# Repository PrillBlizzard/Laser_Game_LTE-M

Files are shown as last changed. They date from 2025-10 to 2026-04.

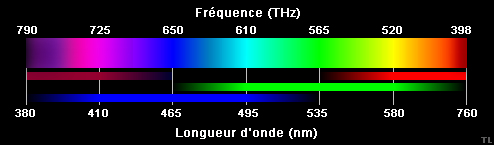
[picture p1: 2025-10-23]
Tests_Hardware/Test_laser_capteur/wavelength-2.png

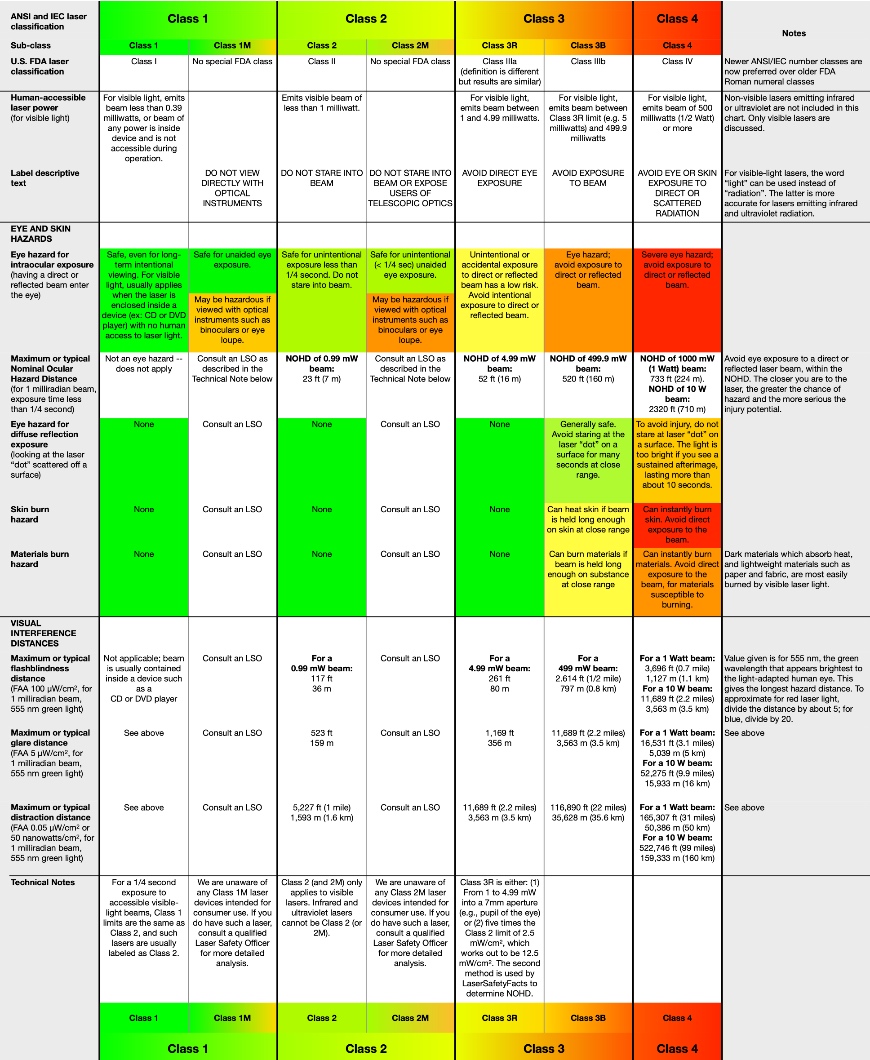
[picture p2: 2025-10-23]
Tests_Hardware/Test_laser_capteur/spreadsheet---laser-classes-870w.jpg

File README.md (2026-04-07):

# Laser_Game_LTE-M
Ce projet à été réalisé dans le cadre de mon projet de fin d'étude (PFE) de ma dernière année d'école d'ingénieur.

## Description
C'est un projet de dévellopement d'un équipement de Laser Game tirant en infrarouge et où l'équipement envoie des données sur un serveur via LTE-M.
Le prototype software est utilisé sur une carte de dévellopement nRF9151-DK.

## Arborescence 
Vous trouverez dans le dossier racine le dossier "Prog_Carte_Globale" correspondant au sur-dossier de l'application créer par l'extension nrfConnect pour VScode.
Vous trouverez aussi dans ce dossier mon compte-rendu de PFE : essentiel pour comprendre ce projet.

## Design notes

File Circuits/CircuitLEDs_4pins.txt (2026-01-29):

$ 1 7.8125e-7 0.1 50 5 43 5e-11
f 304 304 352 304 33 1.5 0.02
R 128 144 80 144 0 0 40 5 0 0 0.5
162 256 144 320 144 2 default-led 0 1 0 0.01
162 256 112 320 112 2 default-led 1 0 0 0.01
162 256 176 320 176 2 default-led 0 0 1 0.01
w 224 144 256 144 0
w 256 112 224 112 0
w 256 176 224 176 0
w 320 176 352 176 0
w 352 144 320 144 0
w 320 112 352 112 0
R 304 304 256 304 4 5 40000 1.8 0 0 0.5
g 352 320 352 384 0 0
w 352 192 352 288 0
r 224 112 128 112 0 100
r 224 144 128 144 0 100
r 224 176 128 176 0 100
w 128 112 128 144 0
w 128 176 128 144 0
w 480 192 480 288 0
g 480 320 480 384 0 0
R 432 304 384 304 4 5 40000 1.8 0 0 0.5
f 432 304 480 304 33 1.5 0.02
f 560 304 608 304 33 1.5 0.02
R 560 304 512 304 4 5 40000 1.8 0 0 0.5
g 608 320 608 384 0 0
w 608 192 608 288 0
w 352 176 352 192 0
w 352 144 480 144 0
w 480 144 480 192 0
w 352 112 608 112 0
w 608 112 608 192 0
o 2 1 0 4099 2.5 0.0125 0 2 2 3

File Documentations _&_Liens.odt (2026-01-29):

Docs :

- Photodiode/photoTransistor : https://www.digikey.fr/fr/articles/how-to-use-photodiodes-and-phototransistors-most-effectively
- https://www.digikey.com/en/articles/the-basics-of-photodiodes-and-phototransistors-and-how-to-apply-them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
- DECT NR+ : https://docs.nordicsemi.com/bundle/ncs-3.0.0/page/nrf/protocols/dect/index.html
  - https://docs.nordicsemi.com/bundle/ncs-3.0.0/page/nrf/app_dev/device_guides/nrf91/index.html#ug-nrf91
  - https://www.digikey.com/en/articles/use-an-lte-m-nb-iot-dect-nr-combination-dev-kit-wireless-iot-design
  - nrf9151 : https://docs.nordicsemi.com/bundle/ncs-3.0.0/page/zephyr/boards/nordic/nrf9151dk/doc/index.html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
  - dtr :
- Aduino pour tests :
  - Interruptions : https://docs.arduino.cc/language-reference/en/functions/external-interrupts/attachInterrupt/
  - Librairies tuto : https://docs.arduino.cc/learn/contributions/arduino-creating-library-guide/
  - I2C tuto : https://www.electronicwings.com/arduino/arduino-i2c
  - I2C librairie : https://github.com/Wh1teRabbitHU/Arduino-I2C/tree/master
  - Librarie réception IR : https://github.com/Arduino-IRremote/Arduino-IRremote/tree/master
- Transmission IR :
  - modulation NEC : https://sibotic.wordpress.com/wp-content/uploads/2013/12/adoh-necinfraredtransmissionprotocol-281113-1713-47344.pdf ou
  - doc recepteur IR ELEGOO Arduino (obsolète) : https://cours.polymtl.ca/inf1900/materiel/capteurs/specEtDoc/PNA4602.pdf
  - https://www.vishay.com/docs/82491/tsop382.pdf plutôt
  - Librairie capteur VCNL3040(DockyDock) : https://github.com/JenertsA/VCNL3040_Proximity_Sensor_Library/tree/master
  - Doc capteur VCNL3040(DockyDock) : https://www.vishay.com/docs/84917/vcnl3040.pdf
- nrf9151 :
  - Pin config : https://docs.nordicsemi.com/bundle/ps_nrf9151/page/pin.html
  - PWM : https://docs.nordicsemi.com/bundle/ps_nrf9151/page/pwm.html
  - Spec Générales : https://docs.nordicsemi.comn/bundle/ps_nrf9151/page/nRF9151_html5_keyfeatures.html (https://docs.nordicsemi.com/bundle/ps_nrf9151/page/nRF9151_html5_keyfeatures.html)

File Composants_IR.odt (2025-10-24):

Photo Transistor :

- https://www.digikey.fr/fr/products/detail/everlight-electronics-co-ltd/ALS-PT204-6C-L177/2675510
  - Traversant
  - Réponse spectral à 650 nm entre 80 % et 100 % ( <10 % entre 550 et 700 nm)
  - Documentation ok : https://eclass.uth.gr/modules/document/file.php/E-CE_U_269/Sensors/Sensors_%20Datasheets/KY-008-AZ-Delivery.pdf
- Optek / TT Electronics — OPB608R
  - https://www.digikey.fr/fr/products/detail/tt-electronics-optek-technology/OPB608R/1636987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

PhotoDiodes (+ rapides) :

- BPW34
  - https://www.digikey.fr/fr/products/detail/ams-osram-usa-inc/BPW34/607274

Diode Laser :

- KY-008 Laser Module
  - Datasheet : https://eclass.uth.gr/modules/document/file.php/E-CE_U_269/Sensors/Sensors_%20Datasheets/KY-008-AZ-Delivery.pdf
  - Où acheter ?
  - https://www.amazon.fr/Aihasd-KY-008-Capteur-Module-Arduino/dp/B00W3GS5Q0

Capteur Arduino :

- https://www.amazon.fr/ARCELI-Commutateur-capteur-r%C3%A9cepteur-Arduino/dp/B07RLNLN37

Résistances 7,5 kOhm

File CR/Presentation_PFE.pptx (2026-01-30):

## Final Project Presentation

Laser Tag System by Gaël Chauvet

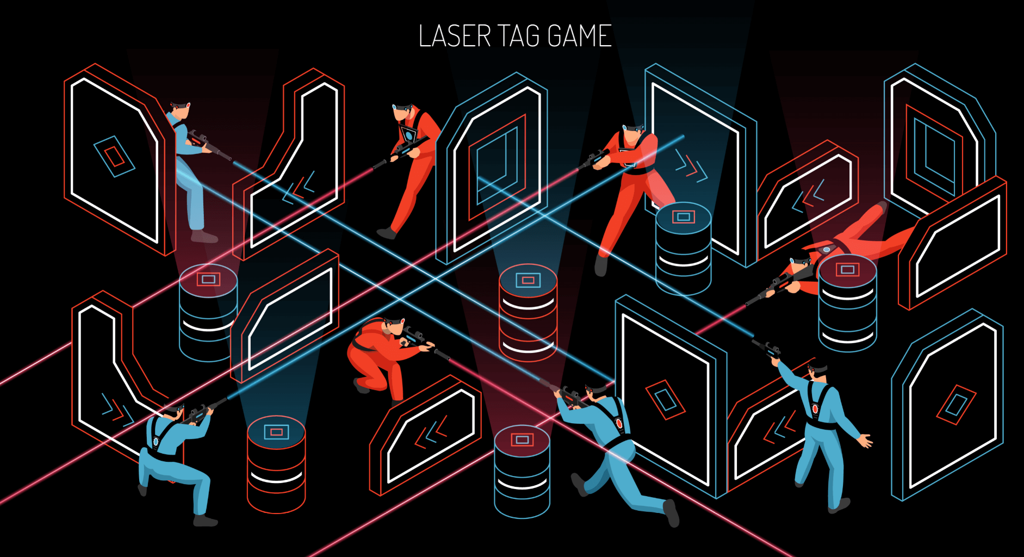
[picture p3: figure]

## Project and system description

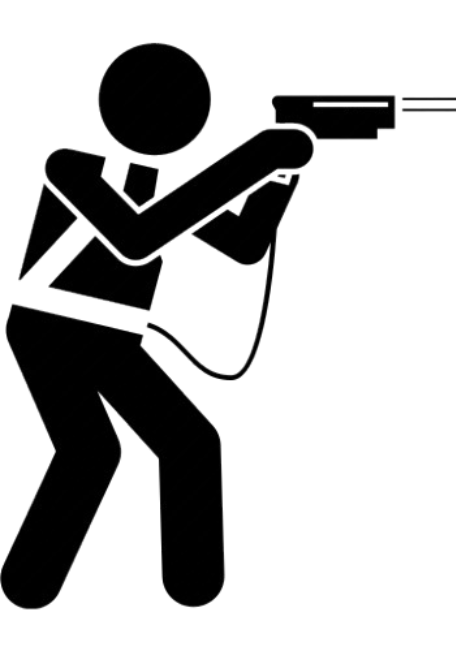
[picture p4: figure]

## Choice of communication Technology

## Choice of communication Technology 2

- IR

- Laser

## Devellopement of communication Technology

## Server stored data

## RGB LEDs

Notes:

.

## Video of functionnality

- feasibility of projet
- (Describing what is happening on the screen)

## Thank you for your attention

## Exemple of code #1

## Exemple of code #2

## Exemple of code #3

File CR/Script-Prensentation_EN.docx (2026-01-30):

Good Afternoon

Today I am here to show you my work, in the context of my end of year project at Codium.

The subject of this project was to design from scratch, a laser game system equipment, that could send and organise game data on a distant server using mobile communication, more precisely LTE-M technology. — the original idea was to use NR+ technology but no libraries or modular software application existed at the time we started the development. Because DECT NR+ is a recent protocol. In fact it was standardized in 2020 and adopted as a 5G standard in 2022.

Now let’s go back to our Laser Game system project and let’s see what this kind of system is made of.
First we have the classic system of an emitter, inside the gun, and receivers scatered accross a homemade jacket, and the gun alike, to detect if the player was hit and to serve as target for the other players.

To this classic system, we add a wireless communication system to send player data to a relatively distant server. The objective of said server is to track players data, scores and follow game statistics as it happens.

Finally, the last and maybe the most important part : the flashing lights ! Because one of the most visible feature of the Laser Game is the actual Laser and all the lights that come with it. Creating an unique atmosphere in wich to play.

I will now describe in more details how we implemented each of those features during the short 28 days dedicated to the project.

About the « shooting » technology, we first undergo some research and find that a French brand of LaserGame claim to use Laser at 100%, to shoot the sensors and communicate. Meanwhile other brands use infra-red (IR) communications, similar of those found in TV remotes and use the Laser for « esthetic » purposes. So we start studying both technology, performing differents tests of range and directivity alike. We end up with a comparison of both technology to help us decide wich way to go.

In said comparison we found that the IR communication seems more reliable than the laser one. The difficulties we had with the photo-transistor used as the sensors for the Laser communication, is that, even if its spectral sensitivity match the wavelenght of the Laser emission, it stays very sensitive to ambient light, and the tests were only conclusive by placing both emitter and receiver in a dark chamber. On the other hand, one of the advantage of the IR technology, is that it is already widely used and for a long time. It is the same kind of technology that the one we find in television remote since the 1980’s : a simple IR diode and a matching receiver.

But the inconvenient of IR is that it is entirely invisible to the naked eye. And it remove the charm of a Laser pointer.

Therefore we decided to design an hybrid system : we use IR components for the communication system and keep the Laser for pointer purposes.

About the IR communication protocol used : we had a wide range of IR protocol for this part. As from the 1980’s big television companies across the world, such as NEC(Japanese), Sony(Japanese) or Phillips(Netherlands) devellopped their own protocol. However the performance tests of the IR technology reveale that the tested equipements already used the NEC IR protocol, therefore as we were already familiar with this protocol we decided to use it.

Now about the devellopement of this features, the first and main difficulty was that there was no libraries directly avaible. The thing was : to test the equipement we used an Arduino as micro-controller because the Arduino community already has a library so we didn’t have to create a new one. But to program our own prototype we needed to use the C programming language and even if the Arduino language is a sub-language of C++, it was uncompatible with our system.

We then proceed to create our own library based on the state machine found in the Arduino library describing the NEC protocol. It was quite difficult, an extensive knowledge of the technology was needed but we finally made it work and it turned out to be quite reliable.

And with this, the first part of the project was complete.

Now let’s talk about the wireless communication between each equipement

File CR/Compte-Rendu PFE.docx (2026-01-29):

# Compte rendu Projet de Fin d’Etudes (PFE) : Système Laser Game

# Connecté

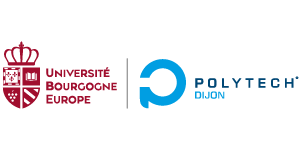
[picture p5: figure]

Sommaire :

Table des figures :

# 1. Introduction au Projet

Ce projet de fin d’étude a été proposé par CODIUM Electronique. Il consiste à développer un système de « laser game » complet, intégrant des composants électroniques embarqués pour les plastrons, les modules d'épaules et le pistolet, avec une connectivité sans fil NR+.

L'objectif principal est de concevoir de A à Z une solution technique fonctionnelle capable de détecter les tirs, d'identifier les tireurs et de transmettre les données de jeu en temps réel à un serveur.

Ce projet peut se décomposer en trois parties majeures :

- La recherche et le développement d’une technologie de « tir » (émission/réception) adaptée.
- La programmation de LEDs particulières pour réagir aux tirs reçus.
- Le développement d’un serveur HTTP et de l’envoi d’informations depuis les cartes vers ce serveur, via la technologie NR+ (finalement LTE-M).

Ce projet a fait appel à des compétences en électronique, mais surtout en programmation pour l’embarqué, à des études de documentation et à une réflexion sur la conception électronique.

## 1.1 Gestion du projet

On organise le projet autour du planning donné dans le sujet de PFE. (Pour rappel) il s’organise autour de quatre mois : d’octobre 2025 à janvier 2026, et suit les grandes étapes décrites ci-dessous :

- Octobre 2025 : L’analyse théorique et les tests du système de tir : on commence par se renseigner sur ce qui existe déjà en termes de système de laser game et les technologies qu’ils utilisent. Puis on commence à faire des tests avec le matériel à notre disposition et la documentation que l’on peut trouver en ligne, pour savoir quelle technologie choisir pour notre système.
- Novembre 2025 : Choix de la technologie, prototypage et tests de performances : une fois l’analyse théorique complète, on fait le choix de la technologie ainsi que du protocole à utiliser. On commande ainsi les composants nécessaires et on les implémente afin d’y conduire des tests. Pour le système de tir, des tests de portées et de directivité sont nécessaires.
- Décembre 2025 : Début de la programmation embarquée : après avoir une émission fonctionnelle, on commence la phase de programmation embarquée sur microcontrôleur. L’objectif ici est de faire réagir le système à la réception d’un tir afin de, dans un premier temps, gérer les LEDs de l’équipement puis, dans un second temps, d’envoyer les informations récupérées à la réception vers un serveur HTTP via le réseau mobile.
- Janvier 2026 : Finalisation de la programmation embarquée : mise en commun de toutes les parties du projet, tests de fonctionnement complet. On assemble les différentes parties du projet et on les teste ensemble afin d’obtenir un prototype fonctionnel.

La phase de conception, de routage et de fabrication d’un prototype hardware a été retirée du planning à la suite de la décision de mon tuteur de PFE. N’ayant qu’un total de 14 semaines (16 semaines en comptant le congé de Noël) et pouvant compter 8 semaines entre la commande et la réception de ces cartes prototypes, il a été préférable de se focaliser sur l’aspect implémentation software des différentes fonctionnalités. Cette phase ainsi que la modélisation 3D de l’équipement étant donc laissées de côté si ce projet est repris ultérieurement.

Pour rappel, nous avions « seulement » 28 jours étalés sur 14 semaines, dédiés à ce projet. Il était difficile de fournir une solution complète et fonctionnelle en plus d’un prototype de carte correctement routée et prête à l’emploi. Un travail à temps plein aurait été adapté afin de fournir une solution complète un peu moins « expérimental » que celle proposée dans ce rapport.

## 1.2 Outils utilisés

Afin de développer une solution et de programmer un prototype software sur le kit de développement du nRF9151 (nRF9151-DK) de Nordic Semiconductor, nous utilisons Visual Studio Code avec l’extension nRF Connect. L'extension nRF Connect est un outil puissant conçu pour faciliter le développement d'applications pour les microcontrôleurs de la série nRF de Nordic Semiconductor. Cette extension intègre des fonctionnalités spécifiques pour le développement de firmware, la configuration matérielle et le débogage des dispositifs nRF. Nous avons également utilisé l’extension DeviceTree, permettant de visualiser les modifications faites sur le DeviceTree de la carte par le biais d’un overlay.

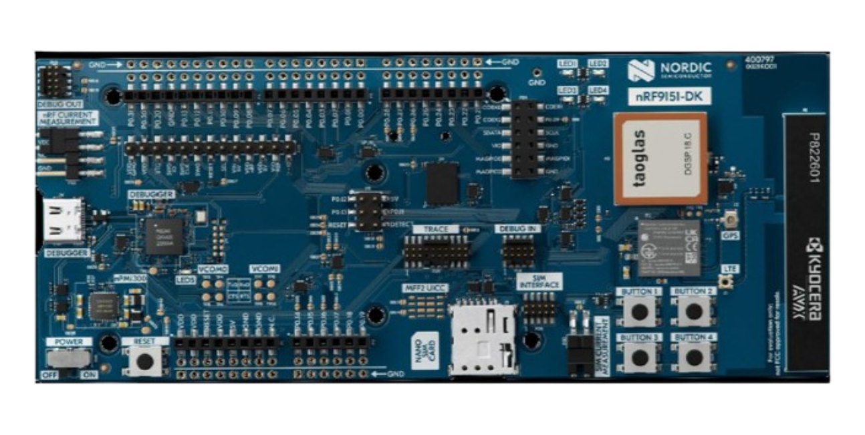
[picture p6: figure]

Figure 1 - nRF 9151 - DK

De plus, afin de programmer le firmware du modem du nRF9151-DK, nous avons utilisé l’outil « nRF Connect for Desktop » installé sur une distribution Ubuntu de Linux, permettant ainsi de gérer directement les installations sur le kit de développement.

# 2. Description du système

Lorsque l’on pense à un équipement, on pense à trois grandes fonctionnalités : la première étant le pistolet et le tir, ainsi que la détection du tir lorsque l’on est touché. Cette fonctionnalité définit le jeu du laser game et est donc essentielle à ce projet. C’est par ailleurs sur cette fonctionnalité que nous passerons le plus de temps. Par la suite, la deuxième fonctionnalité majeure est le suivi du score. Le but du jeu étant de faire le score le plus élevé, il est important d’enregistrer chaque coup au but. Enfin, la troisième fonctionnalité est la gestion des lumières. Une partie de laser game serait moins intéressante sans lasers et sans LEDs qui clignotent pour nous dire que quelqu’un nous a touchés.

C’est autour de ces trois axes que le développement de notre PFE s’est articulé.

## 2.1 Système de « tir » (émission – réception)

### 2.1.1Technologies utilisées

Pour ce qui est de l’émission et de la réception, en première approche, on imagine que l’information se transmet directement par le laser « visible » que l’on voit. En se penchant sur ce sujet, on trouve des entreprises comme « Laser Game Entreprise » annonçant une technologie 100 % laser (en comparaison à des systèmes mélangeant technologie infrarouge (IR) et laser plus classique). On se penche alors sur la recherche de technologie laser pour transmettre l’information.

#### Émission - Réception LASER

On commence des tests d’émission laser à partir de la diode laser KY-008, compatible Arduino, ainsi que son module de réception, équipé d’un phototransistor et d’un circuit anti-rebond.

Les phototransistors sont des composants équivalents à un transistor bipolaire, à l’exception que la base est activée en fonction de la lumière reçue. Ce transistor peut être plus ou moins sensible à certaines longueurs d’ondes. Celui choisi est le plus sensible autour de la longueur d’onde du laser (c’est-à-dire 630 nm).

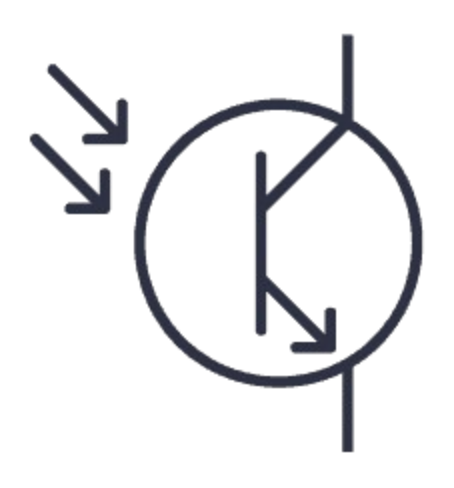
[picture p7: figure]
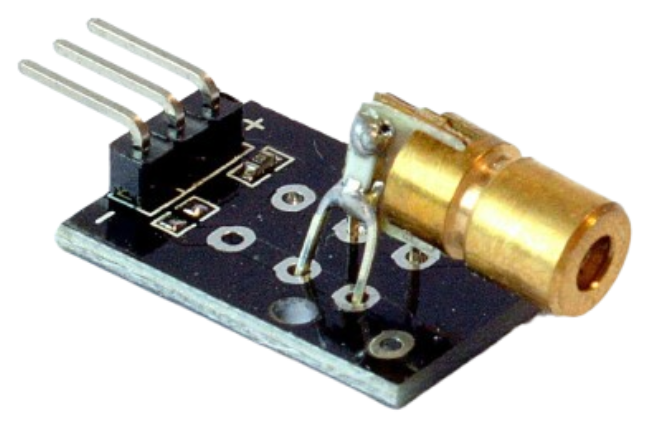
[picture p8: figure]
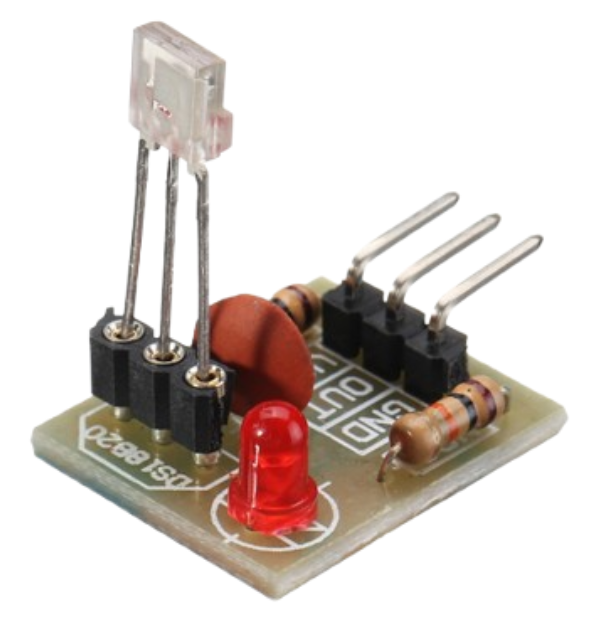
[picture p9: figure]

Figure 2 - Composants Lasers

Les tests ont eu des résultats peu concluants. Le premier facteur limitant est le temps de montée et de descente du phototransistor, ne permettant pas une fréquence de clignotement efficace. Bien que l’on puisse réduire la quantité d’information à envoyer, cette fréquence d’envoi est trop faible. De plus, le laser ayant une puissance <5 mW (pour des raisons de sécurité), la lumière ambiante interfère avec la détection, même à courte portée, rendant la détection du signal laser moins fiable. On arrive à des tests concluants en plaçant le laser dans une chambre sombre avec très peu de lumière, ce qui est loin d’être idéal si l’on veut étendre notre application de laser game à l’extérieur.

Cela dit, la présence du laser est essentielle d’un point de vue pratique, ne serait-ce que pour servir de pointeur laser afin d’indiquer à l’utilisateur la direction de son tir.

#### Émission - Réception IR

À la suite des problématiques rencontrées avec les tests laser, on décide d’essayer les technologies infrarouges (IR) déjà utilisées pour les télécommandes de télévision, par exemple. On commence alors les tests de portée avec un récepteur IR (que l’on identifiera comme TSOP38238), une télécommande IR compatible Arduino, et une carte Arduino Uno. Des bibliothèques Arduino gérant l’émission et la réception IR existaient déjà, il était alors plus facile d’effectuer des tests de performances avec l’Arduino.

Les résultats de ces tests furent concluants : les essais avec plusieurs télécommandes (dont une télécommande de télévision) ont montré que la communication est stable sur une distance convenable. La portée de communication dépend de la puissance fournie par la diode IR. Lors des tests, la distance maximale trouvée est d’environ 10 mètres, correspondant à la longueur du bâtiment, et est jugée suffisante. Pour ce qui est des protocoles de communication, on choisit le protocole de communication NEC, dont je parlerai plus en détail ci-dessous. On choisit par la suite des composants adaptés pour implémenter cette communication. Les principales caractéristiques recherchées sont :

- Pour la diode IR : une bonne puissance d’émission maximale et une émission maximale pour une longueur d’onde correspondant à la sensibilité maximale du récepteur (autour de 950 nm pour le récepteur choisi).
- Pour le capteur IR : une sensibilité maximale autour de la longueur d’onde correspondant à la diode (autour de 900 nm pour la diode IR choisie).

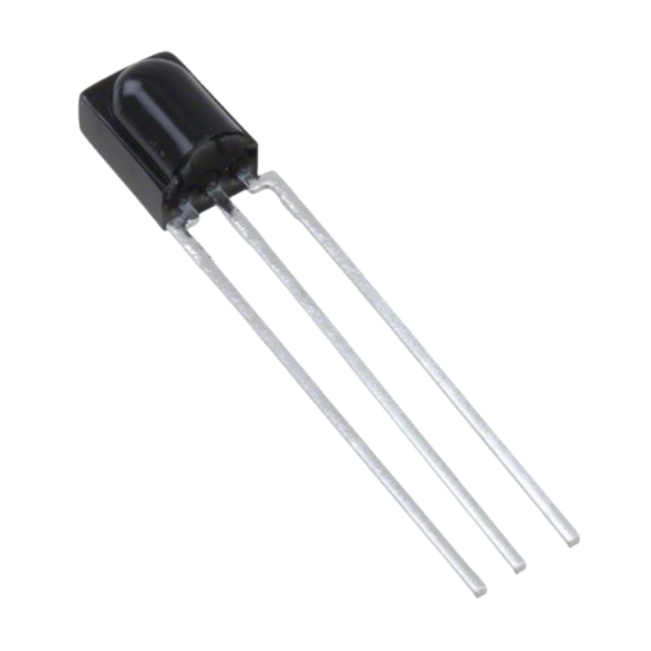
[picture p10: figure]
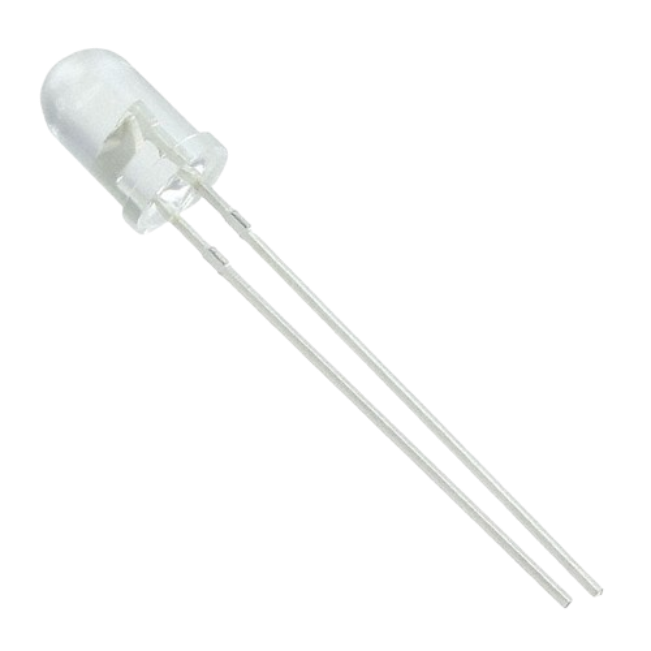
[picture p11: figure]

On choisit alors la diode IR : MT5900-IR avec le récepteur TSOP38238. L’avantage avec ce récepteur infrarouge est qu’il intègre des composants de démodulation intégrés afin de recevoir un signal numérique (tout ou rien) à l’arrivée. Le protocole NEC utilisant un codage par distance d’impulsion avec une porteuse en PWM.

Figure 3 - Composants IR

#### Conclusion

Après avoir étudié et testé ces deux technologies, nous pouvons établir le comparatif suivant :

| LASER | IR
Portée | Dépend de la luminosité ambiante | Suffisante
Directivité | Très directive | Peu directive
Facilité d’implémentation de la communications | Aucunes librairies et documentations accessibles | Documentation et librairie existante
Visible | Oui | Non

Ici, on cherche une technologie fiable et facile d’implémentation au vu du peu de temps accordé à ce projet. La technologie IR serait alors appropriée. Or, l’émetteur IR n’est pas visible à l’œil nu, le joueur ne voyant pas où il tire, cela réduit l’intérêt de cette technologie. On opte alors pour une méthode hybride où l’on installe un pointeur laser afin de « guider » le tir, et la communication est assurée par la technologie IR installée parallèlement à ce pointeur afin d’assurer la précision. Pour réduire la directivité de la LED IR, un « canon » imprimé en 3D peut être envisagé.

## 2.2 Implémentation de l’émission et la réception

### 2.2.1 Hardware

Le capteur a trois broches : une pour 5V, une pour la masse, et une pour la donnée qui est active sur un signal bas. Pour ce qui est de la diode IR, une résistance de 1 kΩ est à ajouter entre l’anode et la sortie GPIO à 1,8 V de la carte.

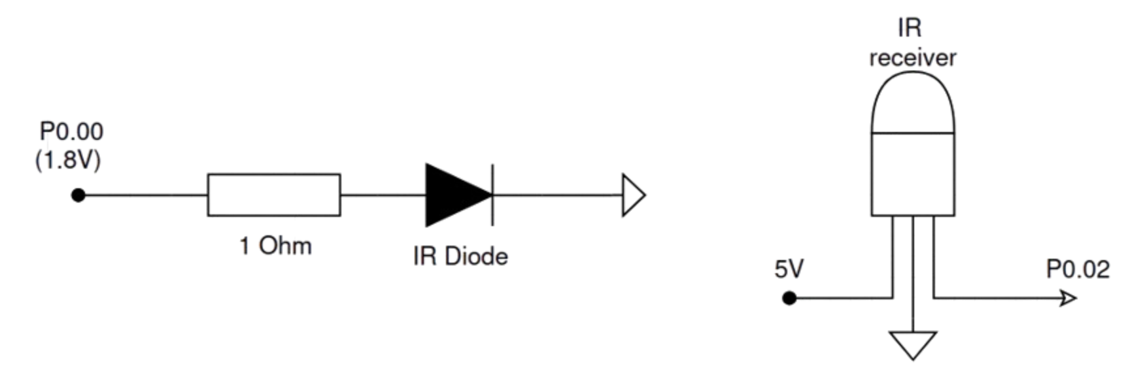
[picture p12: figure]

Figure 4 - Circuits IR

### 2.2.2 Protocole NEC

Pour réaliser la transmission IR, on prend la décision d’utiliser le protocole NEC car il est facile d’utilisation, fiable et bien documenté. Le protocole NEC est un protocole de communication utilisant le codage par durée d’impulsion avec une porteuse de 38 kHz (PWM avec un rapport cyclique de 1/3 ou 1/4 étant conseillé). Pour coder un ‘0’ logique, une impulsion de 560 µs de la porteuse suivie de 560 µs de pause est envoyée. Pour un ‘1’ logique, une impulsion de 560 µs de la porteuse suivie de 1 680 µs de pause est envoyée.

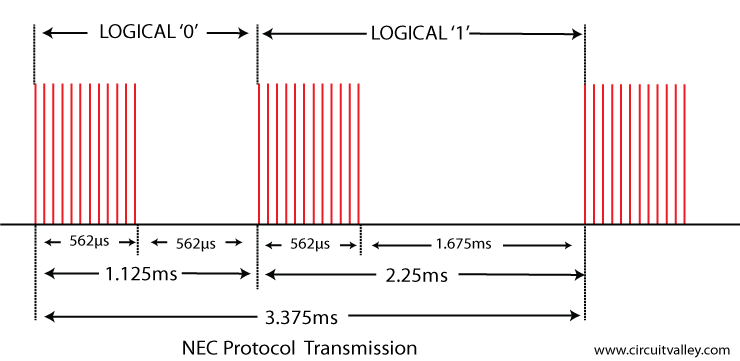
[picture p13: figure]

Figure 5 - NEC : exemple modulation par largeur d'impulsion

De plus, le début de l’algorithme du protocole NEC est composé d’une impulsion longue de 9 ms suivie de 4,5 ms de pause, indiquant au récepteur le début de la transmission. Pour chaque chaîne de 8 bits envoyée, il envoie aussi l’inverse logique de cette dernière, permettant ainsi d’avoir le même nombre de ‘1’ et de ‘0’ dans la trame. Cela crée une trame de longueur fixe et assure une meilleure fiabilité (fonctionnalité que nous n’avons pas implémentée pour avoir une meilleure quantité de données à envoyer).

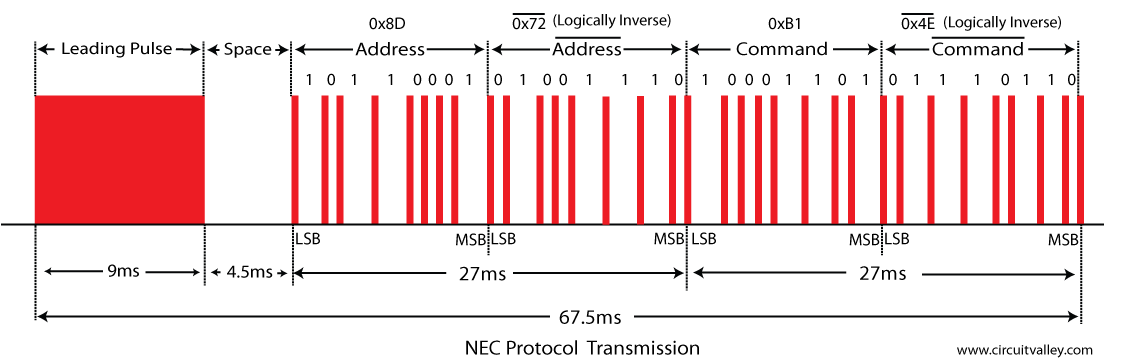
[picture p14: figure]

Figure 6 - Exemple de trame

La seule problématique rencontrée pour l’implémentation de ce protocole sur notre microcontrôleur est que nous n’avons pas trouvé de bibliothèque NEC en C déjà développée. Par conséquent, il a fallu en développer une par nos propres moyens. Ayant le détail de l’algorithme nécessaire à son implémentation dans la bibliothèque Arduino, il suffit d’étudier et de comprendre cette bibliothèque et de l’adapter en C pour le microcontrôleur souhaité. Cette étape a pris un certain temps mais s’est conclue par un succès. Il a fallu adapter la tolérance à cause de l’instabilité de la PWM du microcontrôleur, qui ne s’arrêtait pas et ne s’allumait pas immédiatement au moment idéal (ce qui n’a rien de surprenant), ou à cause du bruit que peut recevoir le capteur.

## 2.3 Gestion des lumières

Pour ce qui est de la gestion des lumières sur l’équipement, nous nous proposons d’utiliser les LEDs RGB SK6812. Ce sont des LEDs RGB composées de trois broches : une pour 5V, une pour GND, et une pour Data.

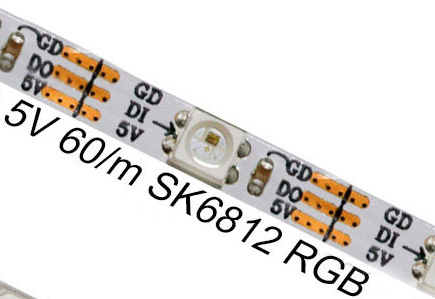
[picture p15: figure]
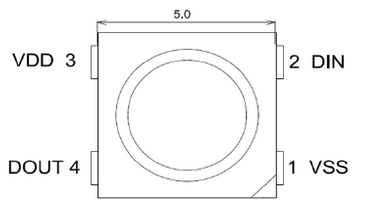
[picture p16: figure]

Figure 7 - LEDs RGB SK6812

La broche Data sert à commander les trois composantes R, G et B via un protocole RZ unipolaire à une fréquence de 800 kHz. Chaque composante est codée sur 8 bits et est envoyée dans l’ordre suivant : vert, rouge, bleu.

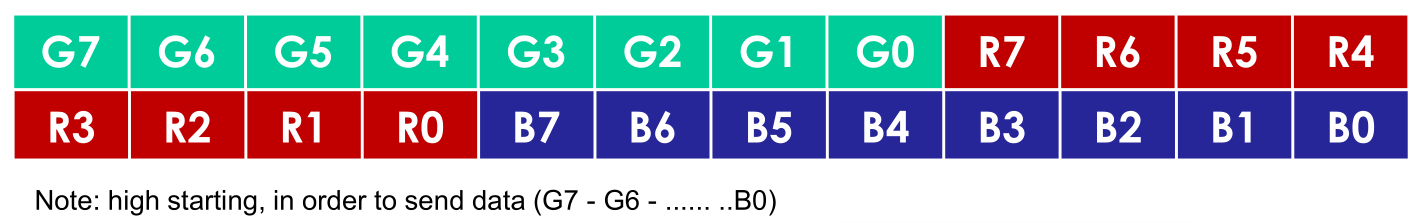
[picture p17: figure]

Figure 8 - Protocole d'envoie des donnés pour la SK6812

Le premier obstacle était l'absence de bibliothèques fonctionnelles et adaptées pour contrôler nos LEDs. Nous avons donc été contraints de développer notre propre bibliothèque. Lors des essais, le principal problème a été la synchronisation de la modulation de largeur d'impulsion (PWM) à la bonne fréquence.

Le microcontrôleur nRF9151 offre plusieurs fréquences de PWM : 16 MHz, 8 MHz, 4 MHz, 2 MHz, 1 MHz, 500 kHz, 250 kHz et 125 kHz. Pour résoudre ce problème, nous avons eu l'idée de sélectionner une fréquence plus élevée, multiple de la fréquence souhaitée, et d'envoyer un nombre de bits plus élevé. Par exemple, en choisissant 4 MHz, qui correspond à 5 fois 800 kHz, il fallait envoyer 5 fois plus de bits. Pour envoyer '01', il fallait envoyer '0000011111'. Cependant, cette approche n'a pas fonctionné, probablement parce que les LEDs ne reconnaissaient pas les 1 et les 0 de la PWM tournant à une fréquence trop élevée.

N'ayant pas obtenu de résultats concluants, nous avons décidé de nous tourner vers des LEDs RGB à 4 broches avec une cathode commune. L'avantage de ce type de LEDs est que les composantes rouge (R), verte (G) et bleue (B) peuvent être commandées indépendamment sur trois broches GPIO différentes. Cela est idéal pour un ensemble de LEDs devant afficher la même couleur. Cependant, cela peut être un désavantage si les broches GPIO viennent à manquer, ce qui n'est pas notre cas.N'ayant pas obtenu de résultats concluants, nous avons décidé de nous tourner vers des LEDs RGB à 4 broches avec une cathode commune. L'avantage de ce type de LEDs est que les composantes rouge (R), verte (G) et bleue (B) peuvent être commandées indépendamment sur trois broches GPIO différentes. Cela est idéal pour un ensemble de LEDs devant afficher la même couleur. Cependant, cela peut être un désavantage si les broches GPIO viennent à manquer, ce qui n'est pas notre cas.

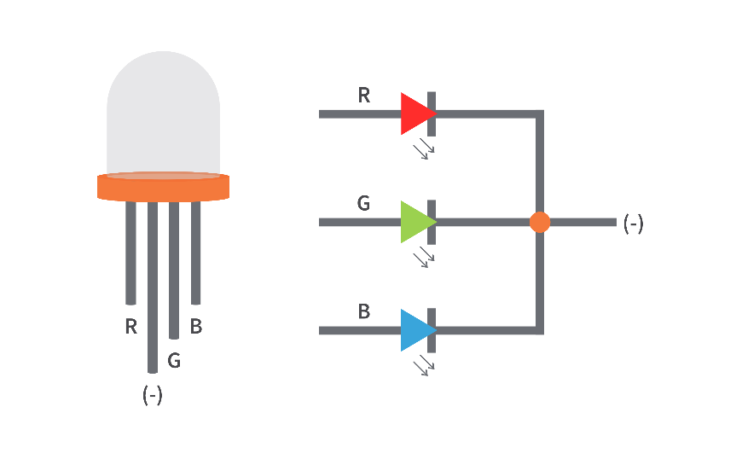
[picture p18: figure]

Figure 9 - Schéma de LED à cathode commune

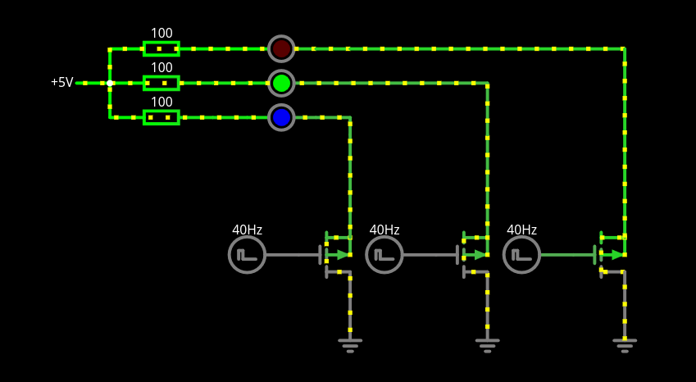
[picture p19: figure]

Figure 10 - Circuit contrôle de LED RGB

Dans le circuit ci-dessus, utilisé pour le prototype, on alimente les LEDs RGB en 5 V et, pour les contrôler, on utilise des transistors MOSFET à canal P. La commande à 1,8 V est reliée à la Grille, les LEDs à la Source et la masse au Drain. En pratique, on utilise un transistor P-MOS IRF9Z34N pour le prototype. On est obligé d’utiliser un P-MOS dans le prototype car les sorties GPIO ne sont qu’à 1,8 V, tandis que les LEDs et la diode laser fonctionnent en 5 V. Sur la carte finale, on pourra ajouter des régulateurs de tension plutôt que des transistors afin de pallier cet obstacle.

## 2.4 Serveur pour le suivi de score

### 2.4.1 Côté Carte

L'objectif ici est de permettre la communication entre la carte microcontrôleur et un serveur distant. Le sujet du PFE spécifie l'utilisation de la technologie NR+, qui est une évolution de la 5G cellulaire. Cependant, étant donné que le NR+ est un protocole de communication relativement récent, il n'existe pas encore de drivers, de bibliothèques ou de stacks pour le piloter. En raison de cette limitation, nous avons décidé de changer de technologie et de passer à la technologie LTE-M, pour laquelle il existe déjà des bibliothèques et des exemples d'utilisation bien documentés par Nordic Semiconductor.

LTE-M est une technologie de communication sans fil conçue spécifiquement pour les dispositifs de l'Internet des objets (IoT). Basée sur la norme LTE (Long Term Evolution), elle offre plusieurs avantages pour les applications IoT. LTE-M est particulièrement efficace en termes d'énergie, ce qui est crucial pour les dispositifs IoT qui doivent souvent fonctionner pendant de longues périodes avec des batteries limitées. Elle bénéficie également de la couverture étendue des réseaux LTE existants, assurant une connectivité fiable même dans des zones rurales ou mal desservies. La technologie utilise une bande passante réduite par rapport aux réseaux LTE traditionnels, ce qui permet de réduire la consommation d'énergie et les coûts de données. Malgré cette réduction de bande passante, LTE-M offre une latence relativement faible, essentielle pour les applications nécessitant une réponse rapide. Les modules LTE-M sont généralement moins chers que les modules LTE traditionnels, réduisant ainsi les coûts de déploiement pour les solutions IoT.

De plus, LTE-M est compatible avec les infrastructures LTE existantes, facilitant son déploiement et son intégration dans les réseaux cellulaires actuels. Elle est optimisée pour les dispositifs IoT, offrant des fonctionnalités spécifiques comme le support des messages courts (SMS) et des alertes de données. Comme toutes les technologies basées sur LTE, LTE-M bénéficie des mêmes niveaux de sécurité et de chiffrement, assurant ainsi la protection des données transmises. Elle offre également des garanties de qualité de service, essentielles pour les applications IoT nécessitant une connectivité fiable et constante.

Pour programmer la carte, nous utilisons une carte SIM IoT que nous branchons à la nRF9151. Cette carte SIM IoT est essentielle pour établir la connexion LTE-M. Nous avons choisi de nous baser sur l'exemple de nRF Connect appelé « HTTP_client » pour récupérer les fonctions essentielles nécessaires à la programmation de notre application. Cet exemple nous fournit une base solide pour envoyer des requêtes HTTP au serveur distant.

En plus de programmer notre application, il est également nécessaire d'utiliser le programmeur « nRF Connect for Desktop » pour flasher le firmware du modem de la nRF9151 DK. Ce firmware est crucial pour assurer une communication stable et efficace entre la carte et le serveur distant. Le processus de flashage du firmware permet de configurer le modem pour qu'il puisse utiliser les fonctionnalités LTE-M.

### 2.4.2 Côté serveur

Pour développer un serveur web capable de récupérer des données envoyées par un microcontrôleur utilisant la technologie LTE-M, nous avons opté pour l'utilisation d'un serveur privé virtuel (VPS) hébergé sur OVH, fourni par Codium. Ce VPS sert de plateforme pour recevoir les requêtes HTTP provenant de la carte microcontrôleur.

Pour la programmation du serveur, nous avons choisi Python en raison de sa simplicité et de sa flexibilité. Plus précisément, nous utilisons le framework Flask, qui facilite grandement la gestion des requêtes HTTP. Flask est particulièrement adapté pour ce type de projet en raison de sa légèreté et de sa capacité à gérer efficacement les routes et les requêtes.

L'utilisation de Python nous permet également de manipuler et de stocker les données reçues de manière aisée. Nous pouvons écrire des scripts pour traiter les données et les enregistrer dans des fichiers spécifiques, ce qui est essentiel pour l'analyse ultérieure. Actuellement, notre application gère les requêtes HTTP GET et POST. La requête POST joue un rôle crucial dans notre système, car elle est utilisée pour envoyer les données de réception du tir au serveur. Ces données sont ensuite traitées et stockées pour une utilisation future, comme la génération de rapports ou l'analyse des performances.

# 4. Améliorations possible

Pour le moment, le projet n’est qu’à l’état de prototype et existe comme preuve de faisabilité. En effet, nous avons utilisé le nRF9151 DK, qui est un kit de développement servant à programmer des applications avec tous les composants nécessaires déjà installés sur la carte. Or, ce kit n’est pas voué à être mis en production en raison de son prix et de son manque de flexibilité. Ainsi, les prochaines étapes du projet sont les suivantes.

## 4.1 Conception de carte

Dans un premier temps, on peut commencer par la conception des cartes. On pourra utiliser le logiciel FreeCAD pour le design et le routage de celles-ci. On imagine ainsi cinq types de cartes afin de créer un système modulaire :

- Carte dos : Cette carte accueillera le microcontrôleur ainsi que l’antenne LTE-M du système. Elle intégrera également quelques capteurs, permettant de créer des cibles dans le dos. Pour des raisons de simplicité, c’est sur cette carte que seront placés les régulateurs de tension, afin de fournir les niveaux adaptés aux différents équipements (capteurs et émetteurs laser IR). Plusieurs connecteurs, disposés sur les bords, permettront la communication et la liaison avec les autres cartes, de manière à ce que les câbles puissent être intégrés dans la doublure d’un éventuel gilet de jeu.
- Cartes épaules : Ces cartes seront stratégiquement placées au niveau des épaules (avant et arrière) des joueurs. Chacune d’elles intégrera un ou plusieurs capteurs, permettant d’ajouter des cibles sur ces zones.
- Carte plastron : Cette carte sera placée au niveau du torse du joueur, intégrant une plus grande quantité de capteurs pour former une zone cible étendue. Elle pourra également faire office de relais pour le connecteur reliant la carte arrière à celle du pistolet.
- Carte Pistolet : Une carte sera placée dans le pistolet du joueur, accueillant l’émetteur laser et l’émetteur IR, installés de manière à être le plus proche possible l’un de l’autre et parfaitement alignés sur le même axe. Le laser servira de pointeur pour le joueur, garantissant que le tir en IR suive avec précision l’axe du laser. Une impression 3D pourra être envisagée pour verrouiller mécaniquement ces deux composants.

Toutes ces cartes seront équipées d’un nombre suffisant de LEDs RGB 4 broches, comme décrit précédemment, afin d’informer le joueur et les joueurs à proximité de son état (notamment s’il a été touché par un autre joueur).

## 4.2 Modélisation 3D

Certaines pièces de l’équipement de laser game peuvent être imprimées en 3D pour assurer une contrainte mécanique efficace des différentes cartes et composants du système. L’objectif est d’intégrer ce système dans un gilet, permettant ainsi au joueur de porter l’équipement de manière confortable et pratique. Pour relier les différentes parties du système, nous utilisons des connecteurs solides mais interchangeables, ce qui améliore la modularité et la flexibilité de l’ensemble

Notamment, des « canons » pour le pistolet ont été conçus et imprimés en 3D pour optimiser la directivité de l’émetteur infrarouge (IR). Cette approche permet non seulement de renforcer la précision de la transmission, mais aussi de garantir une meilleure intégration des composants dans l’équipement final.

# 5. Sources

- Protocole NEC : https://si.blaisepascal.fr/1t-protocole-nec/
- nrf-9151 : https://docs.nordicsemi.com/bundle/ps_nrf9151/page/nRF9151_html5_keyfeatures.html
- Photodiodes & Photos transistors : https://www.digikey.fr/en/articles/the-basics-of-photodiodes-and-phototransistors-and-how-to-apply-them
- DECT NR+ : https://docs.nordicsemi.com/bundle/ncs-3.0.0/page/nrf/protocols/dect/index.html
- Capteur TSOP38438 : https://www.digikey.fr/en/products/detail/vishay-semiconductor-opto-division/TSOP38238/1681362
- Documentation Capteur TSOP38438 : https://www.vishay.com/docs/82491/tsop382.pdf
- Diode IR : https://www.digikey.fr/fr/products/detail/marktech-optoelectronics/MT5900-IR/5956247
- Documentation Diode IR : https://specs.marktechopto.com/pdf/products/datasheet/MT5900-IR.pdf
- Documentation Flask : https://flask.palletsprojects.com/en/stable/
- Github du projet : https://github.com/PrillBlizzard/Laser_Game_NR-_Codium

Polytech Dijon Gaël Chauvet 5A - SE 2025-2026

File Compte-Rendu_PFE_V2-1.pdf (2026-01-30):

Polytech Dijon | Gaël Chauvet 5A - SE | 2025-2026

# Compte rendu Projet de Fin d’Etudes (PFE) : Système Laser Game Connecté

## Sommaire :

1. Introduction au Projet | 3 1.1 Gestion du projet | 3 1.2 Outils utilisés | 4 2. Description du système | 5 2.1 Système de « tir » (émission – réception) | 5 2.1.1Technologies utilisées | 5 Émission - Réception LASER | 6 Émission - Réception IR | 6 Conclusion | 7 2.2 Implémentation de l’émission et la réception | 8 2.2.1 Hardware | 8 2.2.2 Protocole NEC | 8 2.3 Gestion des lumières | 10 2.4 Serveur pour le suivi de score | 12 2.4.1 Côté Carte | 12 2.4.2 Côté serveur | 13 4. Améliorations possible | 14 4.1 Conception de carte | 14 4.2 Modélisation 3D | 15 5. Sources | 16

## Table des figures :

### Figure 1 - nRF 9151 - DK | 5 Figure 2 - Composants Lasers | 6 Figure 3 - Composants IR | 7 Figure 4 - Circuits IR | 8 Figure 5 - NEC : exemple modulation par largeur d'impulsion | 9 Figure 6 - Exemple de trame | 9 Figure 7 - LEDs RGB SK6812 | 10

Figure 8 - Protocole d'envoie des donnés pour la SK6812 | 10

### Figure 9 - Schéma de LED à cathode commune | 11 Figure 10 - Circuit contrôle de LED RGB | 12

## 1. Introduction au Projet

Ce projet de fin d’étude a été proposé par CODIUM Electronique. Il consiste à développer un système de « laser game » complet, intégrant des composants électroniques embarqués pour les plastrons, les modules d'épaules et le pistolet, avec une connectivité sans fil NR+.

L'objectif principal est de concevoir de A à Z une solution technique fonctionnelle capable de détecter les tirs, d'identifier les tireurs et de transmettre les données de jeu en temps réel à un serveur.

Ce projet peut se décomposer en trois parties majeures :

– La recherche et le développement d’une technologie de « tir » (émission/réception) adaptée.
– La programmation de LEDs particulières pour réagir aux tirs reçus.
– Le développement d’un serveur HTTP et de l’envoi d’informations depuis les cartes vers ce serveur, via la technologie NR+ (finalement LTE-M).

Ce projet a fait appel à des compétences en électronique, mais surtout en programmation pour l’embarqué, à des études de documentation et à une réflexion sur la conception électronique.

## 1.1 Gestion du projet

On organise le projet autour du planning donné dans le sujet de PFE. (Pour rappel) il s’organise autour de quatre mois : d’octobre 2025 à janvier 2026, et suit les grandes étapes décrites ci-dessous :

- Octobre 2025 : L’analyse théorique et les tests du système de tir : on commence par se renseigner sur ce qui existe déjà en termes de système de laser game et les technologies qu’ils utilisent. Puis on commence à faire des tests avec le matériel à notre disposition et la documentation que l’on peut trouver en ligne, pour savoir quelle technologie choisir pour notre système.
- Novembre 2025 : Choix de la technologie, prototypage et tests de performances : une fois l’analyse théorique complète, on fait le choix de la technologie ainsi que du protocole à utiliser. On commande ainsi les composants nécessaires et on les implémente afin d’y conduire des tests. Pour le système de tir, des tests de portées et de directivité sont nécessaires.
- Décembre 2025 : Début de la programmation embarquée : après avoir une émission fonctionnelle, on commence la phase de programmation embarquée sur microcontrôleur. L’objectif ici est de faire réagir le système à la réception d’un tir afin de, dans un premier temps, gérer les LEDs de l’équipement puis, dans un second temps, d’envoyer les informations récupérées à la réception vers un serveur HTTP via le réseau mobile.
- Janvier 2026 : Finalisation de la programmation embarquée : mise en commun de toutes les parties du projet, tests de fonctionnement complet. On assemble les différentes parties du projet et on les teste ensemble afin d’obtenir un prototype fonctionnel.

La phase de conception, de routage et de fabrication d’un prototype hardware a été retirée du planning à la suite de la décision de mon tuteur de PFE. N’ayant qu’un total de 14 semaines (16 semaines en comptant le congé de Noël) et pouvant compter 8 semaines entre la commande et la réception de ces cartes prototypes, il a été préférable de se focaliser sur l’aspect implémentation software des différentes fonctionnalités. Cette phase ainsi que la modélisation 3D de l’équipement étant donc laissées de côté si ce projet est repris ultérieurement.

Pour rappel, nous avions « seulement » 28 jours étalés sur 14 semaines, dédiés à ce projet. Il était difficile de fournir une solution complète et fonctionnelle en plus d’un prototype de carte correctement routée et prête à l’emploi. Un travail à temps plein aurait été adapté afin de fournir une solution complète un peu moins « expérimental » que celle proposée dans ce rapport.

## 1.2 Outils utilisés

Afin de développer une solution et de programmer un prototype software sur le kit de développement du nRF9151 (nRF9151-DK) de Nordic Semiconductor, nous utilisons Visual Studio Code avec l’extension nRF Connect. L'extension nRF Connect est un outil puissant conçu pour faciliter le développement d'applications pour les microcontrôleurs de la série nRF de Nordic Semiconductor. Cette extension intègre des fonctionnalités spécifiques pour le développement de firmware, la configuration matérielle et le débogage des dispositifs nRF. Nous avons également utilisé l’extension DeviceTree, permettant de visualiser les modifications faites sur le DeviceTree de la carte par le biais d’un overlay.

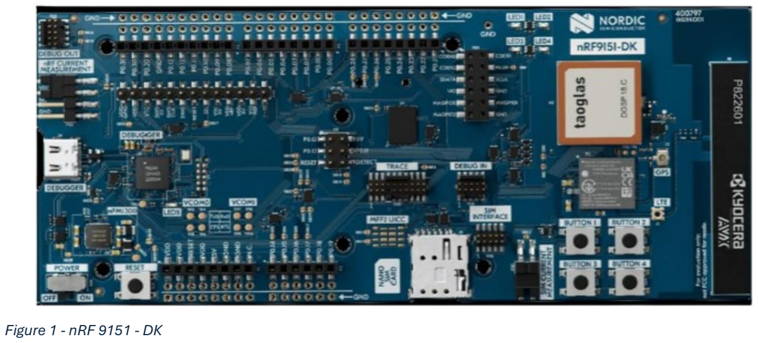
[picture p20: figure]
Figure 1 - nRF 9151 - DK

De plus, afin de programmer le firmware du modem du nRF9151-DK, nous avons utilisé l’outil « nRF Connect for Desktop » installé sur une distribution Ubuntu de Linux, permettant ainsi de gérer directement les installations sur le kit de développement.

## 2. Description du système

Lorsque l’on pense à un équipement, on pense à trois grandes fonctionnalités : la première étant le pistolet et le tir, ainsi que la détection du tir lorsque l’on est touché. Cette fonctionnalité définit le jeu du laser game et est donc essentielle à ce projet. C’est par ailleurs sur cette fonctionnalité que nous passerons le plus de temps. Par la suite, la deuxième fonctionnalité majeure est le suivi du score. Le but du jeu étant de faire le score le plus élevé, il est important d’enregistrer chaque coup au but. Enfin, la troisième fonctionnalité est la gestion des lumières. Une partie de laser game serait moins intéressante sans lasers et sans LEDs qui clignotent pour nous dire que quelqu’un nous a touchés.

C’est autour de ces trois axes que le développement de notre PFE s’est articulé.

## 2.1 Système de « tir » (émission – réception)

2.1.1Technologies utilisées

Pour ce qui est de l’émission et de la réception, en première approche, on imagine que l’information se transmet directement par le laser « visible » que l’on voit. En se penchant sur ce sujet, on trouve des entreprises comme « Laser Game Entreprise » annonçant une technologie 100 % laser (en comparaison à des systèmes mélangeant technologie infrarouge (IR) et laser plus classique). On se penche alors sur la recherche de technologie laser pour transmettre l’information.

Émission - Réception LASER
On commence des tests d’émission laser à partir de la diode laser KY-008, compatible Arduino, ainsi que son module de réception, équipé d’un phototransistor et d’un circuit anti-rebond.

Les phototransistors sont des composants équivalents à un transistor bipolaire, à l’exception que la base est activée en fonction de la lumière reçue. Ce transistor peut être plus ou moins sensible à certaines longueurs d’ondes. Celui choisi est le plus sensible autour de la longueur d’onde du laser (c’est-à-dire 630 nm).

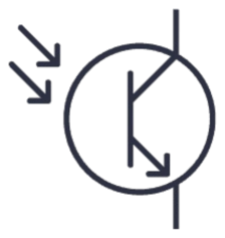
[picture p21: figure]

Figure 2 - Composants Lasers

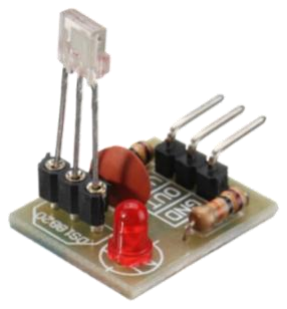
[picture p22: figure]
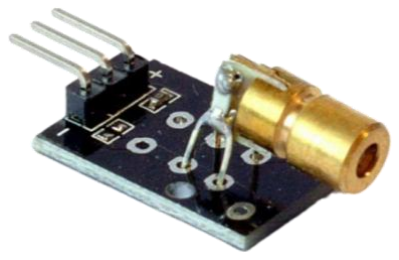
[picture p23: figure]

Les tests ont eu des résultats peu concluants. Le premier facteur limitant est le temps de montée et de descente du phototransistor, ne permettant pas une fréquence de clignotement efficace. Bien que l’on puisse réduire la quantité d’information à envoyer, cette fréquence d’envoi est trop faible. De plus, le laser ayant une puissance <5 mW (pour des raisons de sécurité), la lumière ambiante interfère avec la détection, même à courte portée, rendant la détection du signal laser moins fiable. On arrive à des tests concluants en plaçant le laser dans une chambre sombre avec très peu de lumière, ce qui est loin d’être idéal si l’on veut étendre notre application de laser game à l’extérieur.

Cela dit, la présence du laser est essentielle d’un point de vue pratique, ne serait-ce que pour servir de pointeur laser afin d’indiquer à l’utilisateur la direction de son tir.

Émission - Réception IR
À la suite des problématiques rencontrées avec les tests laser, on décide d’essayer les technologies infrarouges (IR) déjà utilisées pour les télécommandes de télévision, par exemple. On commence alors les tests de portée avec un récepteur IR (que l’on identifiera comme TSOP38238), une télécommande IR compatible Arduino, et une carte Arduino Uno. Des bibliothèques Arduino gérant l’émission et la réception

IR existaient déjà, il était alors plus facile d’effectuer des tests de performances avec l’Arduino.

Les résultats de ces tests furent concluants : les essais avec plusieurs télécommandes (dont une télécommande de télévision) ont montré que la communication est stable sur une distance convenable. La portée de communication dépend de la puissance fournie par la diode IR. Lors des tests, la distance maximale trouvée est d’environ 10 mètres, correspondant à la longueur du bâtiment, et est jugée suffisante. Pour ce qui est des protocoles de communication, on choisit le protocole de communication NEC, dont je parlerai plus en détail ci-dessous. On choisit par la suite des composants adaptés pour implémenter cette communication. Les principales caractéristiques recherchées sont :

- Pour la diode IR : une bonne puissance d’émission maximale et une émission maximale pour une longueur d’onde correspondant à la sensibilité maximale du récepteur (autour de 950 nm pour le récepteur choisi).
- Pour le capteur IR : une sensibilité maximale autour de la longueur d’onde correspondant à la diode (autour de 900 nm pour la diode IR choisie).

On choisit alors la diode IR : MT5900-IR avec le récepteur TSOP38238. L’avantage avec ce récepteur infrarouge est qu’il intègre des composants de démodulation intégrés afin de recevoir un signal numérique (tout ou rien) à l’arrivée. Le protocole NEC utilisant un codage par distance d’impulsion avec une porteuse en PWM.

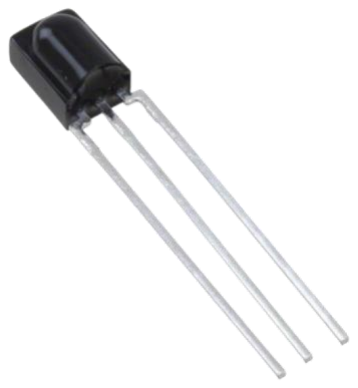
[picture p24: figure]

Conclusion

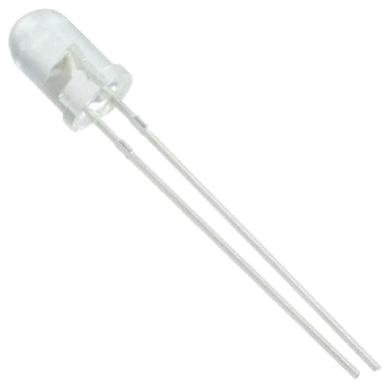
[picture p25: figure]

Après avoir étudié et testé ces deux technologies, nous pouvons établir le comparatif suivant :

Figure 3 - Composants IR

LASER | IR
Portée | Dépend de la luminosité ambiante | Suffisante
Directivité | Très directive | Peu directive
Facilité d’implémentation de la communications | Aucunes librairies et documentations accessibles | Documentation et librairie existante
Visible | Oui | Non

Ici, on cherche une technologie fiable et facile d’implémentation au vu du peu de temps accordé à ce projet. La technologie IR serait alors appropriée. Or, l’émetteur IR n’est pas visible à l’œil nu, le joueur ne voyant pas où il tire, cela réduit l’intérêt de cette technologie. On opte alors pour une méthode hybride où l’on installe un pointeur laser afin de « guider » le tir, et la communication est assurée par la technologie IR installée parallèlement à ce pointeur afin d’assurer la précision. Pour réduire la directivité de la LED IR, un « canon » imprimé en 3D peut être envisagé.

## 2.2 Implémentation de l’émission et la réception

2.2.1 Hardware

Le capteur a trois broches : une pour 5V, une pour la masse, et une pour la donnée qui est active sur un signal bas. Pour ce qui est de la diode IR, une résistance de 1 kΩ est à ajouter entre l’anode et la sortie GPIO à 1,8 V de la carte.

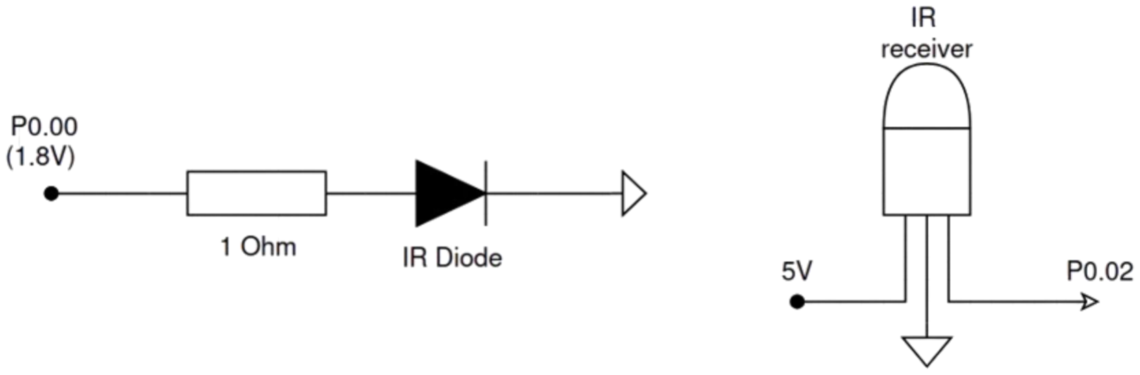
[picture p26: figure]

Figure 4 - Circuits IR

2.2.2 Protocole NEC

Pour réaliser la transmission IR, on prend la décision d’utiliser le protocole NEC car il est facile d’utilisation, fiable et bien documenté. Le protocole NEC est un protocole de communication utilisant le codage par durée d’impulsion avec une porteuse de 38 kHz (PWM avec un rapport cyclique de 1/3 ou 1/4 étant conseillé). Pour coder un ‘0’ logique, une impulsion de 560 µs de la porteuse suivie de 560 µs de pause est envoyée. Pour un ‘1’ logique, une impulsion de 560 µs de la porteuse suivie de 1 680 µs de pause est envoyée.


De plus, le début de l’algorithme du protocole NEC est composé d’une impulsion longue de 9 ms suivie de 4,5 ms de pause, indiquant au récepteur le début de la transmission. Pour chaque chaîne de 8 bits envoyée, il envoie aussi l’inverse logique de cette dernière, permettant ainsi d’avoir le même nombre de ‘1’ et de ‘0’ dans la trame. Cela crée une trame de longueur fixe et assure une meilleure fiabilité (fonctionnalité que nous n’avons pas implémentée pour avoir une meilleure quantité de données à envoyer).

Figure 5 - NEC : exemple modulation par largeur d'impulsion


Figure 6 - Exemple de trame

La seule problématique rencontrée pour l’implémentation de ce protocole sur notre microcontrôleur est que nous n’avons pas trouvé de bibliothèque NEC en C déjà développée. Par conséquent, il a fallu en développer une par nos propres moyens. Ayant le détail de l’algorithme nécessaire à son implémentation dans la bibliothèque Arduino, il suffit d’étudier et de comprendre cette bibliothèque et de l’adapter en C pour le microcontrôleur souhaité. Cette étape a pris un certain temps mais s’est conclue par un succès. Il a fallu adapter la tolérance à cause de l’instabilité de la PWM du microcontrôleur, qui ne s’arrêtait pas et ne s’allumait pas immédiatement au moment idéal (ce qui n’a rien de surprenant), ou à cause du bruit que peut recevoir le capteur.

## 2.3 Gestion des lumières

Pour ce qui est de la gestion des lumières sur l’équipement, nous nous proposons d’utiliser les LEDs RGB SK6812. Ce sont des LEDs RGB composées de trois broches : une pour 5V, une pour GND, et une pour Data.


Figure 7 - LEDs RGB SK6812


La broche Data sert à commander les trois composantes R, G et B via un protocole RZ unipolaire à une fréquence de 800 kHz. Chaque composante est codée sur 8 bits et est envoyée dans l’ordre suivant : vert, rouge, bleu.


Figure 8 - Protocole d'envoie des donnés pour la SK6812

Le premier obstacle était l'absence de bibliothèques fonctionnelles et adaptées pour contrôler nos LEDs. Nous avons donc été contraints de développer notre propre bibliothèque. Lors des essais, le principal problème a été la synchronisation de la modulation de largeur d'impulsion (PWM) à la bonne fréquence.

Le microcontrôleur nRF9151 offre plusieurs fréquences de PWM : 16 MHz, 8 MHz, 4 MHz, 2 MHz, 1 MHz, 500 kHz, 250 kHz et 125 kHz. Pour résoudre ce problème, nous avons eu l'idée de sélectionner une fréquence plus élevée, multiple de la fréquence souhaitée, et d'envoyer un nombre de bits plus élevé. Par exemple, en choisissant 4 MHz, qui correspond à 5 fois 800 kHz, il fallait envoyer 5 fois plus de bits. Pour envoyer '01', il fallait envoyer '0000011111'. Cependant, cette approche n'a pas fonctionné, probablement parce que les LEDs ne reconnaissaient pas les 1 et les 0 de la PWM tournant à une fréquence trop élevée.

N'ayant pas obtenu de résultats concluants, nous avons décidé de nous tourner vers des LEDs RGB à 4 broches avec une cathode commune. L'avantage de ce type de LEDs est que les composantes rouge (R), verte (G) et bleue (B) peuvent être commandées indépendamment sur trois broches GPIO différentes. Cela est idéal pour un ensemble de LEDs devant afficher la même couleur. Cependant, cela peut être un désavantage si les broches GPIO viennent à manquer, ce qui n'est pas notre cas.N'ayant pas obtenu de résultats concluants, nous avons décidé de nous tourner vers des LEDs RGB à 4 broches avec une cathode commune. L'avantage de ce type de LEDs est que les composantes rouge (R), verte (G) et bleue (B) peuvent être commandées indépendamment sur trois broches GPIO différentes. Cela est idéal pour un ensemble de LEDs devant afficher la même couleur. Cependant, cela peut être un désavantage si les broches GPIO viennent à manquer, ce qui n'est pas notre cas.


Figure 9 - Schéma de LED à cathode commune


Dans le circuit ci-dessus, utilisé pour le prototype, on alimente les LEDs RGB en 5 V et, pour les contrôler, on utilise des transistors MOSFET à canal P. La commande à 1,8 V est reliée à la Grille, les LEDs à la Source et la masse au Drain. En pratique, on utilise un transistor P-MOS IRF9Z34N pour le prototype. On est obligé d’utiliser un P-MOS dans le prototype car les sorties GPIO ne sont qu’à 1,8 V, tandis que les LEDs et la diode laser fonctionnent en 5 V. Sur la carte finale, on pourra ajouter des régulateurs de tension plutôt que des transistors afin de pallier cet obstacle.

## 2.4 Serveur pour le suivi de score

2.4.1 Côté Carte

L'objectif ici est de permettre la communication entre la carte microcontrôleur et un serveur distant. Le sujet du PFE spécifie l'utilisation de la technologie NR+, qui est une évolution de la 5G cellulaire. Cependant, étant donné que le NR+ est un protocole de communication relativement récent, il n'existe pas encore de drivers, de bibliothèques ou de stacks pour le piloter. En raison de cette limitation, nous avons décidé de changer de technologie et de passer à la technologie LTE-M, pour laquelle il existe déjà des bibliothèques et des exemples d'utilisation bien documentés par Nordic Semiconductor.

LTE-M est une technologie de communication sans fil conçue spécifiquement pour les dispositifs de l'Internet des objets (IoT). Basée sur la norme LTE (Long Term Evolution), elle offre plusieurs avantages pour les applications IoT. LTE-M est particulièrement efficace en termes d'énergie, ce qui est crucial pour les dispositifs IoT qui doivent souvent fonctionner pendant de longues périodes avec des batteries limitées. Elle bénéficie également de la couverture étendue des réseaux LTE existants,

Figure 10 - Circuit contrôle de LED RGB assurant une connectivité fiable même dans des zones rurales ou mal desservies. La technologie utilise une bande passante réduite par rapport aux réseaux LTE traditionnels, ce qui permet de réduire la consommation d'énergie et les coûts de données. Malgré cette réduction de bande passante, LTE-M offre une latence relativement faible, essentielle pour les applications nécessitant une réponse rapide. Les modules LTE-M sont généralement moins chers que les modules LTE traditionnels, réduisant ainsi les coûts de déploiement pour les solutions IoT.

De plus, LTE-M est compatible avec les infrastructures LTE existantes, facilitant son déploiement et son intégration dans les réseaux cellulaires actuels. Elle est optimisée pour les dispositifs IoT, offrant des fonctionnalités spécifiques comme le support des messages courts (SMS) et des alertes de données. Comme toutes les technologies basées sur LTE, LTE-M bénéficie des mêmes niveaux de sécurité et de chiffrement, assurant ainsi la protection des données transmises. Elle offre également des garanties de qualité de service, essentielles pour les applications IoT nécessitant une connectivité fiable et constante.

Pour programmer la carte, nous utilisons une carte SIM IoT que nous branchons à la nRF9151. Cette carte SIM IoT est essentielle pour établir la connexion LTE-M. Nous avons choisi de nous baser sur l'exemple de nRF Connect appelé « HTTP_client » pour récupérer les fonctions essentielles nécessaires à la programmation de notre application. Cet exemple nous fournit une base solide pour envoyer des requêtes HTTP au serveur distant.

En plus de programmer notre application, il est également nécessaire d'utiliser le programmeur « nRF Connect for Desktop » pour flasher le firmware du modem de la nRF9151 DK. Ce firmware est crucial pour assurer une communication stable et efficace entre la carte et le serveur distant. Le processus de flashage du firmware permet de configurer le modem pour qu'il puisse utiliser les fonctionnalités LTE-M.

2.4.2 Côté serveur

Pour développer un serveur web capable de récupérer des données envoyées par un microcontrôleur utilisant la technologie LTE-M, nous avons opté pour l'utilisation d'un serveur privé virtuel (VPS) hébergé sur OVH, fourni par Codium. Ce VPS sert de plateforme pour recevoir les requêtes HTTP provenant de la carte microcontrôleur.

Pour la programmation du serveur, nous avons choisi Python en raison de sa simplicité et de sa flexibilité. Plus précisément, nous utilisons le framework Flask, qui facilite grandement la gestion des requêtes HTTP. Flask est particulièrement adapté pour ce type de projet en raison de sa légèreté et de sa capacité à gérer efficacement les routes et les requêtes.

L'utilisation de Python nous permet également de manipuler et de stocker les données reçues de manière aisée. Nous pouvons écrire des scripts pour traiter les données et les enregistrer dans des fichiers spécifiques, ce qui est essentiel pour l'analyse ultérieure. Actuellement, notre application gère les requêtes HTTP GET et POST. La requête POST joue un rôle crucial dans notre système, car elle est utilisée pour envoyer les données de réception du tir au serveur. Ces données sont ensuite traitées et stockées pour une utilisation future, comme la génération de rapports ou l'analyse des performances.

## 4. Améliorations possible

Pour le moment, le projet n’est qu’à l’état de prototype et existe comme preuve de faisabilité. En effet, nous avons utilisé le nRF9151 DK, qui est un kit de développement servant à programmer des applications avec tous les composants nécessaires déjà installés sur la carte. Or, ce kit n’est pas voué à être mis en production en raison de son prix et de son manque de flexibilité. Ainsi, les prochaines étapes du projet sont les suivantes.

## 4.1 Conception de carte

Dans un premier temps, on peut commencer par la conception des cartes. On pourra utiliser le logiciel FreeCAD pour le design et le routage de celles-ci. On imagine ainsi cinq types de cartes afin de créer un système modulaire :

- Carte dos : Cette carte accueillera le microcontrôleur ainsi que l’antenne LTE-M du système. Elle intégrera également quelques capteurs, permettant de créer des cibles dans le dos. Pour des raisons de simplicité, c’est sur cette carte que seront placés les régulateurs de tension, afin de fournir les niveaux adaptés aux différents équipements (capteurs et émetteurs laser IR). Plusieurs connecteurs, disposés sur les bords, permettront la communication et la liaison avec les autres cartes, de manière à ce que les câbles puissent être intégrés dans la doublure d’un éventuel gilet de jeu.
- Cartes épaules : Ces cartes seront stratégiquement placées au niveau des épaules (avant et arrière) des joueurs. Chacune d’elles intégrera un ou plusieurs capteurs, permettant d’ajouter des cibles sur ces zones.
- Carte plastron : Cette carte sera placée au niveau du torse du joueur, intégrant une plus grande quantité de capteurs pour former une zone cible étendue. Elle pourra également faire office de relais pour le connecteur reliant la carte arrière à celle du pistolet.
- Carte Pistolet : Une carte sera placée dans le pistolet du joueur, accueillant l’émetteur laser et l’émetteur IR, installés de manière à être le plus proche possible l’un de l’autre et parfaitement alignés sur le même axe. Le laser servira de pointeur pour le joueur, garantissant que le tir en IR suive avec précision l’axe du laser. Une impression 3D pourra être envisagée pour verrouiller mécaniquement ces deux composants.

Toutes ces cartes seront équipées d’un nombre suffisant de LEDs RGB 4 broches, comme décrit précédemment, afin d’informer le joueur et les joueurs à proximité de son état (notamment s’il a été touché par un autre joueur).

## 4.2 Modélisation 3D

Certaines pièces de l’équipement de laser game peuvent être imprimées en 3D pour assurer une contrainte mécanique efficace des différentes cartes et composants du système. L’objectif est d’intégrer ce système dans un gilet, permettant ainsi au joueur de porter l’équipement de manière confortable et pratique. Pour relier les différentes parties du système, nous utilisons des connecteurs solides mais interchangeables, ce qui améliore la modularité et la flexibilité de l’ensemble

Notamment, des « canons » pour le pistolet ont été conçus et imprimés en 3D pour optimiser la directivité de l’émetteur infrarouge (IR). Cette approche permet non seulement de renforcer la précision de la transmission, mais aussi de garantir une meilleure intégration des composants dans l’équipement final.

## 5. Sources

- Protocole NEC :
https://si.blaisepascal.fr/1t-protocole-nec/
- nrf-9151 :
https://docs.nordicsemi.com/bundle/ps_nrf9151/page/nRF9151_html5_keyfeat ures.html (https://docs.nordicsemi.com/bundle/ps_nrf9151/page/nRF9151_html5_keyfeatures.html)
- Photodiodes & Photos transistors : https://www.digikey.fr/en/articles/the-basics-of-photodiodes-and-phototransistors-and-how-to-apply-them (https://www.digikey.fr/en/articles/the-basics-of-photodiodes-and-phototransistors-and-how-to-apply-them)
- DECT NR+ :
https://docs.nordicsemi.com/bundle/ncs-3.0.0/page/nrf/protocols/dect/index.html (https://docs.nordicsemi.com/bundle/ncs-3.0.0/page/nrf/protocols/dect/index.html)
- Capteur TSOP38438 :
https://www.digikey.fr/en/products/detail/vishay-semiconductor-opto-division/TSOP38238/1681362 (https://www.digikey.fr/en/products/detail/vishay-semiconductor-opto-division/TSOP38238/1681362)
- Documentation Capteur TSOP38438 : https://www.vishay.com/docs/82491/tsop382.pdf
- Diode IR :
https://www.digikey.fr/fr/products/detail/marktech-optoelectronics/MT5900-IR/5956247 (https://www.digikey.fr/fr/products/detail/marktech-optoelectronics/MT5900-IR/5956247)
- Documentation Diode IR : https://specs.marktechopto.com/pdf/products/datasheet/MT5900-IR.pdf
- Documentation Flask :
https://flask.palletsprojects.com/en/stable/
- Github du projet :
https://github.com/PrillBlizzard/Laser_Game_NR-_Codium

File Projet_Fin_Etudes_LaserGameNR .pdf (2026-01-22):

# Projet de Fin d'Études – Système Laser Game Connecté

## Encadrant : Émile LAVEY

## Société : Codium Electronique

## Période : Octobre 2025 – Février 2026 (2 jours/semaine)

## Spécialité : Informatique et Électronique

## 1. Contexte et objectifs du projet

Le projet vise à concevoir un système complet de laser game, intégrant l’électronique embarquée pour les plastrons, les modules d’épaules et les pistolets, avec une connectivité sans fil NR+. L’objectif est de créer une solution technique fonctionnelle capable de gérer la détection des tirs, l’identification du tireur, et la transmission des données de jeu en temps réel.

📏 Problématique de portée
Les systèmes actuels de laser game souffrent d’une portée restreinte, ce qui impose la construction de salles à plusieurs niveaux ou espaces cloisonnés pour garantir la couverture radio. Cela complique l’architecture du jeu, limite la flexibilité des terrains et augmente les coûts d’installation. La technologie DECT NR+, standardisée comme réseau privé type 5G, permet une portée significativement améliorée :
- Théorique : jusqu’à 600 m en ligne de vue, et jusqu’à 6,2 km dans des conditions idéales
- Pratique : environ 250 m en environnement intérieur (obstacles, murs) .
Une portée pratique de ~250 m permettrait de couvrir une grande salle à un seul niveau, sans rehausse ou cloisonnement, tout en assurant une fiabilité radio (>99,99 % de livraison de paquets, latence <1 ms) . Cela simplifie la conception du terrain et améliore l’expérience utilisateur.

## 2. Démarche projet

Étape 1 : Étude théorique

a. Détection des tirs
- Analyse des capteurs infrarouges (photodiodes, filtres optiques) et modulation du signal.
- Ciblage des composants assurant précision, portée et réponse rapide.
b. Identification du tireur
- Développement d’un protocole d’encodage IR pour transmettre l’ID du pistolet.
- Validation des performances de reconnaissance dans un environnement multi-joueurs.

Étape 2 : Conception électronique

a. POC sur table
- Mise en place d’un banc de test pour vérifier détection IR, portée, identification.
- Mesure empirique des distances réelles d’émission/réception.
b. Cartes électroniques
- Conception des PCBs pour plastron, épaules et pistolet.
- Intégration d’un module NR+ (ex. nRF9151) et antenne adaptée.
- Optimisation ergonomique et énergétique.

Étape 3 : Développement embarqué
- Programmation des microcontrôleurs (STM32, ESP32…).
- Pilotage IR : émission, réception, décodage.
- Communication via NR+ : échanges fiable, gestion du réseau mesh.
- Logique de jeu : gestion des points, états, synchro.

Étape 4 : Fonctions complémentaires (Extras)

a. Modélisation 3D
- Modélisation des boîtiers intégrant électronique et ergonomie.
- Prototypage par impression 3D.
b. Afficheur de score en temps réel
- Intégration d’écran (OLED, TFT, LED) pour visualiser le score/état du joueur.

c. Sélection d’équipe
- Ajout d’un sélecteur (bouton, NFC…) et rétro-éclairage LED RGB selon l’équipe choisie.

## 3. Compétences mobilisées

- Électronique analogique / numérique : capteurs IR, circuits radio.
- PCB design avec KiCad, Altium, etc.
- Programmation embarquée : C/C++, interruption, protocoles.
- Conception 3D : Fusion 360, SolidWorks.
- Communications sans fil : DECT NR+ mesh.
- Gestion technique de projet : plan, documentation, prototypage.

## 4. Planning prévisionnel

Mois | Activité principale
Octobre 2025 Analyse théorique, composants IR et radio
Novembre | Prototype IR + identification, tests de portée
Décembre | Conception et routage des cartes électroniques
Janvier 2026 Programmation embarquée et intégration NR+ Février Modèle 3D, dashboard de score, démonstration finale

## 5. Livrables attendus

- Cahier des charges et études théoriques.
- Schémas, PCBs, fichiers fabrication.
- Code source commenté et testé.
- Prototype complet fonctionnel.
- Modèles 3D et documentation utilisateur.
- Présentation finale avec démonstration.

## 6. Conclusion

Ce projet combine électronique, développement embarqué, radio mesh et conception produit. L’adoption de la technologie DECT NR+, avec sa portée pratique (~250 m) et sa robustesse (<1 ms, >99,99 % fiabilité), permet d’optimiser l’expérience laser game en un terrain unique à niveau, simplifiant la logistique et améliorant l’immersion.

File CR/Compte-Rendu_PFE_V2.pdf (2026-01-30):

Polytech Dijon | Gaël Chauvet 5A - SE | 2025-2026

# Compte rendu Projet de Fin d’Etudes (PFE) : Système Laser Game Connecté

## Sommaire :

1. Introduction au Projet | 5 1.1 Gestion du projet | 6 1.2 Outils utilisés | 7 2. Description du système | 8 2.1 Système de « tir » (émission – réception) | 9 2.1.1Technologies utilisées | 9 Émission - Réception LASER | 10 Émission - Réception IR | 10 Conclusion | 11 2.2 Implémentation de l’émission et la réception | 12

2.2.1 Hardware | Erreur ! Signet non défini.
2.2.2 Protocole NEC | Erreur ! Signet non défini.
2.3 Gestion des lumières | Erreur ! Signet non défini.
2.4 Serveur pour le suivi de score | Erreur ! Signet non défini.
2.4.1 Côté Carte | Erreur ! Signet non défini.
2.4.2 Côté serveur | Erreur ! Signet non défini.
4. Améliorations possible | Erreur ! Signet non défini.
4.1 Conception de carte | Erreur ! Signet non défini.
4.2 Modélisation 3D | Erreur ! Signet non défini.
5. Sources | Erreur ! Signet non défini.

## Table des figures :

### Figure 1 - nRF 9151 - DK | 5 Figure 2 - Composants Lasers | 6 Figure - Composants IR | 7 Figure - Circuits IR | 8 Figure - NEC : exemple modulation par largeur d'impulsion | 9 Figure - Exemple de trame | 9 Figure - LEDs RGB SK6812 | 10

Figure - Protocole d'envoie des donnés pour la SK6812 | 10

### Figure 9 - Schéma de LED à cathode commune | 11 Figure 10 - Circuit contrôle de LED RGB | 12

## 1. Introduction au Projet

Ce projet de fin d’étude a été proposé par CODIUM Electronique. Il consiste à développer un système de « laser game » complet, intégrant des composants électroniques embarqués pour les plastrons, les modules d'épaules et le pistolet, avec une connectivité sans fil NR+.

L'objectif principal est de concevoir de A à Z une solution technique fonctionnelle capable de détecter les tirs, d'identifier les tireurs et de transmettre les données de jeu en temps réel à un serveur.

Ce projet peut se décomposer en trois parties majeures :

– La recherche et le développement d’une technologie de « tir » (émission/réception) adaptée.
– La programmation de LEDs particulières pour réagir aux tirs reçus.
– Le développement d’un serveur HTTP et de l’envoi d’informations depuis les cartes vers ce serveur, via la technologie NR+ (finalement LTE-M).

Ce projet a fait appel à des compétences en électronique, mais surtout en programmation pour l’embarqué, à des études de documentation et à une réflexion sur la conception électronique.

## 1.1 Gestion du projet

On organise le projet autour du planning donné dans le sujet de PFE. (Pour rappel) il s’organise autour de quatre mois : d’octobre 2025 à janvier 2026, et suit les grandes étapes décrites ci-dessous :

- Octobre 2025 : L’analyse théorique et les tests du système de tir : on commence par se renseigner sur ce qui existe déjà en termes de système de laser game et les technologies qu’ils utilisent. Puis on commence à faire des tests avec le matériel à notre disposition et la documentation que l’on peut trouver en ligne, pour savoir quelle technologie choisir pour notre système.
- Novembre 2025 : Choix de la technologie, prototypage et tests de performances : une fois l’analyse théorique complète, on fait le choix de la technologie ainsi que du protocole à utiliser. On commande ainsi les composants nécessaires et on les implémente afin d’y conduire des tests. Pour le système de tir, des tests de portées et de directivité sont nécessaires.
- Décembre 2025 : Début de la programmation embarquée : après avoir une émission fonctionnelle, on commence la phase de programmation embarquée sur microcontrôleur. L’objectif ici est de faire réagir le système à la réception d’un tir afin de, dans un premier temps, gérer les LEDs de l’équipement puis, dans un second temps, d’envoyer les informations récupérées à la réception vers un serveur HTTP via le réseau mobile.
- Janvier 2026 : Finalisation de la programmation embarquée : mise en commun de toutes les parties du projet, tests de fonctionnement complet. On assemble les différentes parties du projet et on les teste ensemble afin d’obtenir un prototype fonctionnel.

La phase de conception, de routage et de fabrication d’un prototype hardware a été retirée du planning à la suite de la décision de mon tuteur de PFE. N’ayant qu’un total de 14 semaines (16 semaines en comptant le congé de Noël) et pouvant compter 8 semaines entre la commande et la réception de ces cartes prototypes, il a été préférable de se focaliser sur l’aspect implémentation software des différentes fonctionnalités. Cette phase ainsi que la modélisation 3D de l’équipement étant donc laissées de côté si ce projet est repris ultérieurement.

Pour rappel, nous avions « seulement » 28 jours étalés sur 14 semaines, dédiés à ce projet. Il était difficile de fournir une solution complète et fonctionnelle en plus d’un prototype de carte correctement routée et prête à l’emploi. Un travail à temps plein aurait été adapté afin de fournir une solution complète un peu moins « expérimental » que celle proposée dans ce rapport.

## 1.2 Outils utilisés

Afin de développer une solution et de programmer un prototype software sur le kit de développement du nRF9151 (nRF9151-DK) de Nordic Semiconductor, nous utilisons Visual Studio Code avec l’extension nRF Connect. L'extension nRF Connect est un outil puissant conçu pour faciliter le développement d'applications pour les microcontrôleurs de la série nRF de Nordic Semiconductor. Cette extension intègre des fonctionnalités spécifiques pour le développement de firmware, la configuration matérielle et le débogage des dispositifs nRF. Nous avons également utilisé l’extension DeviceTree, permettant de visualiser les modifications faites sur le DeviceTree de la carte par le biais d’un overlay.

Figure 1 - nRF 9151 - DK

De plus, afin de programmer le firmware du modem du nRF9151-DK, nous avons utilisé l’outil « nRF Connect for Desktop » installé sur une distribution Ubuntu de Linux, permettant ainsi de gérer directement les installations sur le kit de développement.

## 2. Description du système

Lorsque l’on pense à un équipement, on pense à trois grandes fonctionnalités : la première étant le pistolet et le tir, ainsi que la détection du tir lorsque l’on est touché. Cette fonctionnalité définit le jeu du laser game et est donc essentielle à ce projet. C’est par ailleurs sur cette fonctionnalité que nous passerons le plus de temps. Par la suite, la deuxième fonctionnalité majeure est le suivi du score. Le but du jeu étant de faire le score le plus élevé, il est important d’enregistrer chaque coup au but. Enfin, la troisième fonctionnalité est la gestion des lumières. Une partie de laser game serait moins intéressante sans lasers et sans LEDs qui clignotent pour nous dire que quelqu’un nous a touchés.

C’est autour de ces trois axes que le développement de notre PFE s’est articulé.

## 2.1 Système de « tir » (émission – réception)

2.1.1Technologies utilisées

Pour ce qui est de l’émission et de la réception, en première approche, on imagine que l’information se transmet directement par le laser « visible » que l’on voit. En se penchant sur ce sujet, on trouve des entreprises comme « Laser Game Entreprise » annonçant une technologie 100 % laser (en comparaison à des systèmes mélangeant technologie infrarouge (IR) et laser plus classique). On se penche alors sur la recherche de technologie laser pour transmettre l’information.

Émission - Réception LASER
On commence des tests d’émission laser à partir de la diode laser KY-008, compatible Arduino, ainsi que son module de réception, équipé d’un phototransistor et d’un circuit anti-rebond.

Les phototransistors sont des composants équivalents à un transistor bipolaire, à l’exception que la base est activée en fonction de la lumière reçue. Ce transistor peut être plus ou moins sensible à certaines longueurs d’ondes. Celui choisi est le plus sensible autour de la longueur d’onde du laser (c’est-à-dire 630 nm).


Figure 2 - Composants Lasers


Les tests ont eu des résultats peu concluants. Le premier facteur limitant est le temps de montée et de descente du phototransistor, ne permettant pas une fréquence de clignotement efficace. Bien que l’on puisse réduire la quantité d’information à envoyer, cette fréquence d’envoi est trop faible. De plus, le laser ayant une puissance <5 mW (pour des raisons de sécurité), la lumière ambiante interfère avec la détection, même à courte portée, rendant la détection du signal laser moins fiable. On arrive à des tests concluants en plaçant le laser dans une chambre sombre avec très peu de lumière, ce qui est loin d’être idéal si l’on veut étendre notre application de laser game à l’extérieur.

Cela dit, la présence du laser est essentielle d’un point de vue pratique, ne serait-ce que pour servir de pointeur laser afin d’indiquer à l’utilisateur la direction de son tir.

Émission - Réception IR
À la suite des problématiques rencontrées avec les tests laser, on décide d’essayer les technologies infrarouges (IR) déjà utilisées pour les télécommandes de télévision, par exemple. On commence alors les tests de portée avec un récepteur IR (que l’on identifiera comme TSOP38238), une télécommande IR compatible Arduino, et une carte Arduino Uno. Des bibliothèques Arduino gérant l’émission et la réception

IR existaient déjà, il était alors plus facile d’effectuer des tests de performances avec l’Arduino.

Les résultats de ces tests furent concluants : les essais avec plusieurs télécommandes (dont une télécommande de télévision) ont montré que la communication est stable sur une distance convenable. La portée de communication dépend de la puissance fournie par la diode IR. Lors des tests, la distance maximale trouvée est d’environ 10 mètres, correspondant à la longueur du bâtiment, et est jugée suffisante. Pour ce qui est des protocoles de communication, on choisit le protocole de communication NEC, dont je parlerai plus en détail ci-dessous. On choisit par la suite des composants adaptés pour implémenter cette communication. Les principales caractéristiques recherchées sont :

- Pour la diode IR : une bonne puissance d’émission maximale et une émission maximale pour une longueur d’onde correspondant à la sensibilité maximale du récepteur (autour de 950 nm pour le récepteur choisi).
- Pour le capteur IR : une sensibilité maximale autour de la longueur d’onde correspondant à la diode (autour de 900 nm pour la diode IR choisie).

On choisit alors la diode IR : MT5900-IR avec le récepteur TSOP38238. L’avantage avec ce récepteur infrarouge est qu’il intègre des composants de démodulation intégrés afin de recevoir un signal numérique (tout ou rien) à l’arrivée. Le protocole NEC utilisant un codage par distance d’impulsion avec une porteuse en PWM.


Conclusion


Après avoir étudié et testé ces deux technologies, nous pouvons établir le comparatif suivant :

Figure 3 - Composants IR

LASER | IR
Portée | Dépend de la luminosité ambiante | Suffisante
Directivité | Très directive | Peu directive
Facilité d’implémentation de la communications | Aucunes librairies et documentations accessibles | Documentation et librairie existante
Visible | Oui | Non

Ici, on cherche une technologie fiable et facile d’implémentation au vu du peu de temps accordé à ce projet. La technologie IR serait alors appropriée. Or, l’émetteur IR n’est pas visible à l’œil nu, le joueur ne voyant pas où il tire, cela réduit l’intérêt de cette technologie. On opte alors pour une méthode hybride où l’on installe un pointeur laser afin de « guider » le tir, et la communication est assurée par la technologie IR installée parallèlement à ce pointeur afin d’assurer la précision. Pour réduire la directivité de la LED IR, un « canon » imprimé en 3D peut être envisagé.

## 2.2 Implémentation de l’émission et la réception

2.2.1 Hardware

Le capteur a trois broches : une pour 5V, une pour la masse, et une pour la donnée qui est active sur un signal bas. Pour ce qui est de la diode IR, une résistance de 1 kΩ est à ajouter entre l’anode et la sortie GPIO à 1,8 V de la carte.


Figure 4 - Circuits IR

2.2.2 Protocole NEC

Pour réaliser la transmission IR, on prend la décision d’utiliser le protocole NEC car il est facile d’utilisation, fiable et bien documenté. Le protocole NEC est un protocole de communication utilisant le codage par durée d’impulsion avec une porteuse de 38 kHz (PWM avec un rapport cyclique de 1/3 ou 1/4 étant conseillé). Pour coder un ‘0’ logique, une impulsion de 560 µs de la porteuse suivie de 560 µs de pause est envoyée. Pour un ‘1’ logique, une impulsion de 560 µs de la porteuse suivie de 1 680 µs de pause est envoyée.


De plus, le début de l’algorithme du protocole NEC est composé d’une impulsion longue de 9 ms suivie de 4,5 ms de pause, indiquant au récepteur le début de la transmission. Pour chaque chaîne de 8 bits envoyée, il envoie aussi l’inverse logique de cette dernière, permettant ainsi d’avoir le même nombre de ‘1’ et de ‘0’ dans la trame. Cela crée une trame de longueur fixe et assure une meilleure fiabilité (fonctionnalité que nous n’avons pas implémentée pour avoir une meilleure quantité de données à envoyer).

Figure 5 - NEC : exemple modulation par largeur d'impulsion


Figure 6 - Exemple de trame

La seule problématique rencontrée pour l’implémentation de ce protocole sur notre microcontrôleur est que nous n’avons pas trouvé de bibliothèque NEC en C déjà développée. Par conséquent, il a fallu en développer une par nos propres moyens. Ayant le détail de l’algorithme nécessaire à son implémentation dans la bibliothèque Arduino, il suffit d’étudier et de comprendre cette bibliothèque et de l’adapter en C pour le microcontrôleur souhaité. Cette étape a pris un certain temps mais s’est conclue par un succès. Il a fallu adapter la tolérance à cause de l’instabilité de la PWM du microcontrôleur, qui ne s’arrêtait pas et ne s’allumait pas immédiatement au moment idéal (ce qui n’a rien de surprenant), ou à cause du bruit que peut recevoir le capteur.

## 2.3 Gestion des lumières

Pour ce qui est de la gestion des lumières sur l’équipement, nous nous proposons d’utiliser les LEDs RGB SK6812. Ce sont des LEDs RGB composées de trois broches : une pour 5V, une pour GND, et une pour Data.


Figure 7 - LEDs RGB SK6812


La broche Data sert à commander les trois composantes R, G et B via un protocole RZ unipolaire à une fréquence de 800 kHz. Chaque composante est codée sur 8 bits et est envoyée dans l’ordre suivant : vert, rouge, bleu.


Figure 8 - Protocole d'envoie des donnés pour la SK6812

Le premier obstacle était l'absence de bibliothèques fonctionnelles et adaptées pour contrôler nos LEDs. Nous avons donc été contraints de développer notre propre bibliothèque. Lors des essais, le principal problème a été la synchronisation de la modulation de largeur d'impulsion (PWM) à la bonne fréquence.

Le microcontrôleur nRF9151 offre plusieurs fréquences de PWM : 16 MHz, 8 MHz, 4 MHz, 2 MHz, 1 MHz, 500 kHz, 250 kHz et 125 kHz. Pour résoudre ce problème, nous avons eu l'idée de sélectionner une fréquence plus élevée, multiple de la fréquence souhaitée, et d'envoyer un nombre de bits plus élevé. Par exemple, en choisissant 4 MHz, qui correspond à 5 fois 800 kHz, il fallait envoyer 5 fois plus de bits. Pour envoyer '01', il fallait envoyer '0000011111'. Cependant, cette approche n'a pas fonctionné, probablement parce que les LEDs ne reconnaissaient pas les 1 et les 0 de la PWM tournant à une fréquence trop élevée.

N'ayant pas obtenu de résultats concluants, nous avons décidé de nous tourner vers des LEDs RGB à 4 broches avec une cathode commune. L'avantage de ce type de LEDs est que les composantes rouge (R), verte (G) et bleue (B) peuvent être commandées indépendamment sur trois broches GPIO différentes. Cela est idéal pour un ensemble de LEDs devant afficher la même couleur. Cependant, cela peut être un désavantage si les broches GPIO viennent à manquer, ce qui n'est pas notre cas.N'ayant pas obtenu de résultats concluants, nous avons décidé de nous tourner vers des LEDs RGB à 4 broches avec une cathode commune. L'avantage de ce type de LEDs est que les composantes rouge (R), verte (G) et bleue (B) peuvent être commandées indépendamment sur trois broches GPIO différentes. Cela est idéal pour un ensemble de LEDs devant afficher la même couleur. Cependant, cela peut être un désavantage si les broches GPIO viennent à manquer, ce qui n'est pas notre cas.


Figure 9 - Schéma de LED à cathode commune


Dans le circuit ci-dessus, utilisé pour le prototype, on alimente les LEDs RGB en 5 V et, pour les contrôler, on utilise des transistors MOSFET à canal P. La commande à 1,8 V est reliée à la Grille, les LEDs à la Source et la masse au Drain. En pratique, on utilise un transistor P-MOS IRF9Z34N pour le prototype. On est obligé d’utiliser un P-MOS dans le prototype car les sorties GPIO ne sont qu’à 1,8 V, tandis que les LEDs et la diode laser fonctionnent en 5 V. Sur la carte finale, on pourra ajouter des régulateurs de tension plutôt que des transistors afin de pallier cet obstacle.

## 2.4 Serveur pour le suivi de score

2.4.1 Côté Carte

L'objectif ici est de permettre la communication entre la carte microcontrôleur et un serveur distant. Le sujet du PFE spécifie l'utilisation de la technologie NR+, qui est une évolution de la 5G cellulaire. Cependant, étant donné que le NR+ est un protocole de communication relativement récent, il n'existe pas encore de drivers, de bibliothèques ou de stacks pour le piloter. En raison de cette limitation, nous avons décidé de changer de technologie et de passer à la technologie LTE-M, pour laquelle il existe déjà des bibliothèques et des exemples d'utilisation bien documentés par Nordic Semiconductor.

LTE-M est une technologie de communication sans fil conçue spécifiquement pour les dispositifs de l'Internet des objets (IoT). Basée sur la norme LTE (Long Term Evolution), elle offre plusieurs avantages pour les applications IoT. LTE-M est particulièrement efficace en termes d'énergie, ce qui est crucial pour les dispositifs IoT qui doivent souvent fonctionner pendant de longues périodes avec des batteries limitées. Elle bénéficie également de la couverture étendue des réseaux LTE existants,

Figure 10 - Circuit contrôle de LED RGB assurant une connectivité fiable même dans des zones rurales ou mal desservies. La technologie utilise une bande passante réduite par rapport aux réseaux LTE traditionnels, ce qui permet de réduire la consommation d'énergie et les coûts de données. Malgré cette réduction de bande passante, LTE-M offre une latence relativement faible, essentielle pour les applications nécessitant une réponse rapide. Les modules LTE-M sont généralement moins chers que les modules LTE traditionnels, réduisant ainsi les coûts de déploiement pour les solutions IoT.

De plus, LTE-M est compatible avec les infrastructures LTE existantes, facilitant son déploiement et son intégration dans les réseaux cellulaires actuels. Elle est optimisée pour les dispositifs IoT, offrant des fonctionnalités spécifiques comme le support des messages courts (SMS) et des alertes de données. Comme toutes les technologies basées sur LTE, LTE-M bénéficie des mêmes niveaux de sécurité et de chiffrement, assurant ainsi la protection des données transmises. Elle offre également des garanties de qualité de service, essentielles pour les applications IoT nécessitant une connectivité fiable et constante.

Pour programmer la carte, nous utilisons une carte SIM IoT que nous branchons à la nRF9151. Cette carte SIM IoT est essentielle pour établir la connexion LTE-M. Nous avons choisi de nous baser sur l'exemple de nRF Connect appelé « HTTP_client » pour récupérer les fonctions essentielles nécessaires à la programmation de notre application. Cet exemple nous fournit une base solide pour envoyer des requêtes HTTP au serveur distant.

En plus de programmer notre application, il est également nécessaire d'utiliser le programmeur « nRF Connect for Desktop » pour flasher le firmware du modem de la nRF9151 DK. Ce firmware est crucial pour assurer une communication stable et efficace entre la carte et le serveur distant. Le processus de flashage du firmware permet de configurer le modem pour qu'il puisse utiliser les fonctionnalités LTE-M.

2.4.2 Côté serveur

Pour développer un serveur web capable de récupérer des données envoyées par un microcontrôleur utilisant la technologie LTE-M, nous avons opté pour l'utilisation d'un serveur privé virtuel (VPS) hébergé sur OVH, fourni par Codium. Ce VPS sert de plateforme pour recevoir les requêtes HTTP provenant de la carte microcontrôleur.

Pour la programmation du serveur, nous avons choisi Python en raison de sa simplicité et de sa flexibilité. Plus précisément, nous utilisons le framework Flask, qui facilite grandement la gestion des requêtes HTTP. Flask est particulièrement adapté pour ce type de projet en raison de sa légèreté et de sa capacité à gérer efficacement les routes et les requêtes.

L'utilisation de Python nous permet également de manipuler et de stocker les données reçues de manière aisée. Nous pouvons écrire des scripts pour traiter les données et les enregistrer dans des fichiers spécifiques, ce qui est essentiel pour l'analyse ultérieure. Actuellement, notre application gère les requêtes HTTP GET et POST. La requête POST joue un rôle crucial dans notre système, car elle est utilisée pour envoyer les données de réception du tir au serveur. Ces données sont ensuite traitées et stockées pour une utilisation future, comme la génération de rapports ou l'analyse des performances.

## 4. Améliorations possible

Pour le moment, le projet n’est qu’à l’état de prototype et existe comme preuve de faisabilité. En effet, nous avons utilisé le nRF9151 DK, qui est un kit de développement servant à programmer des applications avec tous les composants nécessaires déjà installés sur la carte. Or, ce kit n’est pas voué à être mis en production en raison de son prix et de son manque de flexibilité. Ainsi, les prochaines étapes du projet sont les suivantes.

## 4.1 Conception de carte

Dans un premier temps, on peut commencer par la conception des cartes. On pourra utiliser le logiciel FreeCAD pour le design et le routage de celles-ci. On imagine ainsi cinq types de cartes afin de créer un système modulaire :

- Carte dos : Cette carte accueillera le microcontrôleur ainsi que l’antenne LTE-M du système. Elle intégrera également quelques capteurs, permettant de créer des cibles dans le dos. Pour des raisons de simplicité, c’est sur cette carte que seront placés les régulateurs de tension, afin de fournir les niveaux adaptés aux différents équipements (capteurs et émetteurs laser IR). Plusieurs connecteurs, disposés sur les bords, permettront la communication et la liaison avec les autres cartes, de manière à ce que les câbles puissent être intégrés dans la doublure d’un éventuel gilet de jeu.
- Cartes épaules : Ces cartes seront stratégiquement placées au niveau des épaules (avant et arrière) des joueurs. Chacune d’elles intégrera un ou plusieurs capteurs, permettant d’ajouter des cibles sur ces zones.
- Carte plastron : Cette carte sera placée au niveau du torse du joueur, intégrant une plus grande quantité de capteurs pour former une zone cible étendue. Elle pourra également faire office de relais pour le connecteur reliant la carte arrière à celle du pistolet.
- Carte Pistolet : Une carte sera placée dans le pistolet du joueur, accueillant l’émetteur laser et l’émetteur IR, installés de manière à être le plus proche possible l’un de l’autre et parfaitement alignés sur le même axe. Le laser servira de pointeur pour le joueur, garantissant que le tir en IR suive avec précision l’axe du laser. Une impression 3D pourra être envisagée pour verrouiller mécaniquement ces deux composants.

Toutes ces cartes seront équipées d’un nombre suffisant de LEDs RGB 4 broches, comme décrit précédemment, afin d’informer le joueur et les joueurs à proximité de son état (notamment s’il a été touché par un autre joueur).

## 4.2 Modélisation 3D

Certaines pièces de l’équipement de laser game peuvent être imprimées en 3D pour assurer une contrainte mécanique efficace des différentes cartes et composants du système. L’objectif est d’intégrer ce système dans un gilet, permettant ainsi au joueur de porter l’équipement de manière confortable et pratique. Pour relier les différentes parties du système, nous utilisons des connecteurs solides mais interchangeables, ce qui améliore la modularité et la flexibilité de l’ensemble

Notamment, des « canons » pour le pistolet ont été conçus et imprimés en 3D pour optimiser la directivité de l’émetteur infrarouge (IR). Cette approche permet non seulement de renforcer la précision de la transmission, mais aussi de garantir une meilleure intégration des composants dans l’équipement final.

## 5. Sources

- Protocole NEC :
https://si.blaisepascal.fr/1t-protocole-nec/
- nrf-9151 :
https://docs.nordicsemi.com/bundle/ps_nrf9151/page/nRF9151_html5_keyfeat ures.html (https://docs.nordicsemi.com/bundle/ps_nrf9151/page/nRF9151_html5_keyfeatures.html)
- Photodiodes & Photos transistors : https://www.digikey.fr/en/articles/the-basics-of-photodiodes-and-phototransistors-and-how-to-apply-them (https://www.digikey.fr/en/articles/the-basics-of-photodiodes-and-phototransistors-and-how-to-apply-them)
- DECT NR+ :
https://docs.nordicsemi.com/bundle/ncs-3.0.0/page/nrf/protocols/dect/index.html (https://docs.nordicsemi.com/bundle/ncs-3.0.0/page/nrf/protocols/dect/index.html)
- Capteur TSOP38438 :
https://www.digikey.fr/en/products/detail/vishay-semiconductor-opto-division/TSOP38238/1681362 (https://www.digikey.fr/en/products/detail/vishay-semiconductor-opto-division/TSOP38238/1681362)
- Documentation Capteur TSOP38438 : https://www.vishay.com/docs/82491/tsop382.pdf
- Diode IR :
https://www.digikey.fr/fr/products/detail/marktech-optoelectronics/MT5900-IR/5956247 (https://www.digikey.fr/fr/products/detail/marktech-optoelectronics/MT5900-IR/5956247)
- Documentation Diode IR : https://specs.marktechopto.com/pdf/products/datasheet/MT5900-IR.pdf
- Documentation Flask :
https://flask.palletsprojects.com/en/stable/
- Github du projet :
https://github.com/PrillBlizzard/Laser_Game_NR-_Codium

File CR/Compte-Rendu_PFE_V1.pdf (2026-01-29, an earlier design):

Polytech Dijon | Gaël Chauvet 5A - SE | 2025-2026

# Compte rendu Projet de Fin d’Etudes (PFE) : Système Laser Game Connecté

## Sommaire :

1. Introduction au Projet : | 3 1.1 Gestion du projet : | 3 1.2 Outils utilisés | 4 2. Description du système | 5 2.1 Système de « tir » (émission – réception) | 5 2.1.1Technologies utilisées | 5 Émission - Réception LASER | 5 Émission - Réception IR | 6 Conclusion : | 7 2.2 Implémentation de l’émission et la réception | 8 2.2.1 Hardware : | 8 2.2.2 Protocole NEC | 8 2.3 Gestion des lumières | 10 2.4 Serveur pour le suivi de score | 11 2.4.1 Côté Carte | 11 2.4.2 Côté serveur | 12 4. Améliorations possible | 13 4.1 Conception de carte | 13 4.2 Modélisation 3D | 14 5. Sources | 15

## Table des figures :

Figure 1 - Composants Lasers | 6 Figure 2 - Composants IR | 7 Figure 3 - Circuits IR | 8 Figure 4 - NEC : exemple modulation par largeur d'impulsion | 9 Figure 5 - Exemple de trame | 9 Figure 6 - LEDs RGB SK6812 | 10 Figure 7 - Protocole d'envoie des donnés pour la SK6812 | 10 Figure 8 - Shéma de LED à cathode comune | 11 Figure 9 - Logo Flask | 12

## 1. Introduction au Projet :

Ce projet de fin d’étude a été proposé par CODIUM Electronique. Il consiste à développer un système de « laser game » complet, intégrant des composants électroniques embarqués pour les plastrons, les modules d'épaules et le pistolet, avec une connectivité sans fil NR+.

L'objectif principal est de concevoir de A à Z, une solution technique fonctionnelle capable de détecter les tirs, d'identifier les tireurs et de transmettre les données de jeu en temps réel à un serveur.

Ce projet peut se décomposer en 3 parties majeures :

– La recherche et le développement d’une technologie de « tir » (émission/réception) adapté.
– La programmation de LEDs particulières pour réagir au tirs reçus
– Le développement d’un serveur HTTP et de l’envoie d’informations depuis les cartes, vers ce serveur, via la technologie NR+ (finalement LTE-M).

Ce projet a fait appel à des compétences d’électroniques, mais surtout de programmation pour l’embarquer, d’études de de documentations et de réflexion sur la conception électronique.

## 1.1 Gestion du projet :

On organise le projet autour du planning donné dans le sujet de PFE. (Pour
rappel) il s’organise autour de 4 mois : de Octobre 2025 à Janvier 2026, et suit les grandes

### étapes décrites ci-dessous :

### - Octobre 2025 : L’analyse théorique et les tests du système de tir : on commence par se renseigner sur ce qu’il existe déjà en termes de système de Laser Game et les technologies qu’ils utilisent. Puis on commence à faire des tests avec le

matériel à notre disposition et la documentation que l’on peut trouver en ligne, pour savoir quelle technologie choisir pour notre système.

- Novembre 2025 : Choix de la technologie, prototypage et tests de performances : une fois l’analyse théorique complète, on fait le choix de la technologie ainsi que du protocole à utiliser. On commande ainsi les composants nécessaires et on les implémente afin d’y conduire des tests. Pour le système de tir, des tests de

portées et de directivité sont nécessaires.

### - Décembre 2025 : Début de la programmation embarqué : après avoir une émission fonctionnelle, on commence la phase de programmation embarqué sur

### micro-contrôleur. L’objectif ici et de faire réagir le système à la réception d’un tir afin de, dans un premier temps gérer les LEDs de l’équipement puis dans un second temps d’envoyer les informations récupérées à la réception vers un

serveur HTTP via le réseau mobile.

### - Janvier 2026 : Finalisation de la programmation embarquée : mise en commun de toutes les parties du projets, tests de fonctionnement complet. On assemble les différentes parties du projet. Et on les tests ensembles afin d’obtenir un prototype

fonctionnel.

### La phase de conception, de routage, et de fabrication d’un prototype hardware fut

retirée du planning à la suite de la décision de mon tuteur de PFE. N’ayant qu’un total de

### 14 semaines (16 semaines en comptant le congé de Noël) et pouvant compter 8 semaines entre la commande et la réception de ces cartes prototypes, il a été préférable

de se focaliser sur l’aspect implémentation software des différentes fonctionnalités.

### Cette phase ainsi que la modélisation 3D de l’équipement étant donc laissé si ce projet

est repris ultérieurement.

Pour rappel nous avions « seulement » 28 jours étalés sur 14 semaines, dédiés à ce projet. Il était difficile de fournir une solution complète et fonctionnelle en plus d’un prototype de carte correctement routée et prête à l’emploi. Un travail à temps pleins aurait été adapté afin de fournir une solution complète un peu moins « expérimental » que

celle proposé dans ce rapport.

## 1.2 Outils utilisés

Afin de développer une solution et de programmer un prototype software sur le kit de développement du nrf9151 (nrf9151-DK), de Nordic Semiconductor. Nous utilisons Visual Studio Code avec l’extension nrf Connect. L'extension nRF Connect est un outil puissant conçu pour faciliter le développement d'applications pour les microcontrôleurs de la série nRF de Nordic Semiconductor. Cette extension intègre des fonctionnalités spécifiques pour le développement de firmware, la configuration matérielle, et le

débogage des dispositifs nRF. Nous avons aussi utiliser l’extension DeviceTree, permettant de visualiser les modifications faites sur le devictree de la carte par le biais d’un overlay.

### De plus afin de programmer le firmware du modem du nrf9151-DK, nous avons

utilisé l’outil « nrf connect for Desktop » installé sur une distribution ubuntu de linux, permettant ainsi de gérer directement les installations sur le développement kit.

## 2. Description du système

### Lorsque l’on pense à un équipement on pense à 3 grande fonctionnalité : la

première étant le pistolet et le tir ainsi que la détection du tir lorsque l’on est touché. Cette fonctionnalité définit le jeu du Laser Game et est donc essentiel à ce projet. C’est par ailleurs sur cette fonctionnalité que nous passerons le plus de temps. Par la suite, la deuxième fonctionnalité majeure est le suivi du score, le but du jeu étant de faire le score

### le plus élevé, il est important d’enregistrer chaque coup au but. Enfin, la troisième fonctionnalité est la gestion des lumières. Une partie de Laser Game moins intéressant

lasers et sans LEDs qui clignote pour nous dire que quelqu’un nous a touché.
C’est autour de ces 3 axes que le développement de notre PFE s’est articuler.

## 2.1 Système de « tir» (émission – réception)

2.1.1Technologies utilisées

Pour ce qui est de l’émission et de la réception, en première approche, on imagine que l’information se transmet directement le laser « visible » que l’on voit, en se penchant sur ce sujet, on trouve des entreprises comme « Laser Game Entreprise » annonçant une technologie 100% LASER (en comparaison à des systèmes mélangeant technologie infrarouge (IR) et LASER plus classique). On se penche alors sur la recherche de technologie LASER pour transmettre l’information.

Émission - Réception LASER
On commence des tests d’émission laser à partir de la diode LASER KY-008, compatible Arduino. Ainsi que son module de réception, équipé d’un photo-transistor et d’un circuit anti-rebond.

Les photos-transistors sont des composants équivalent à un transistor bipolaire à l’exception que la base est activé en fonction de la lumière reçue. Ce transistor peut être plus ou moins sensible à certaines longueurs d’ondes. Celui


choisie est le plus sensible autour de la longueur d’onde du LASER (càd. 630 nm ).


Figure 1 - Composants Lasers


Les tests ont eu des résultats peu concluants, le premier facteur limitant étant le temps de monté et de descente du photo-transistor, ne permettant une fréquence de clignotement efficace. Bien que l’on puisse réduire la quantité d’information à envoyer, cette fréquence d’envoi est trop faible. De plus le laser ayant une puissance <5mW (pour des raisons de sécurités) la lumière ambiante interfère avec la détection même à courte portée, rendant la détection du signal laser moins fiable. On arrive à des tests concluant qu’en plaçant le LASER dans un chambre sombre avec que très peu de lumière ce qui est loin d’être idéal si on veut étendre notre application de Laser Game à l’extérieur.
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

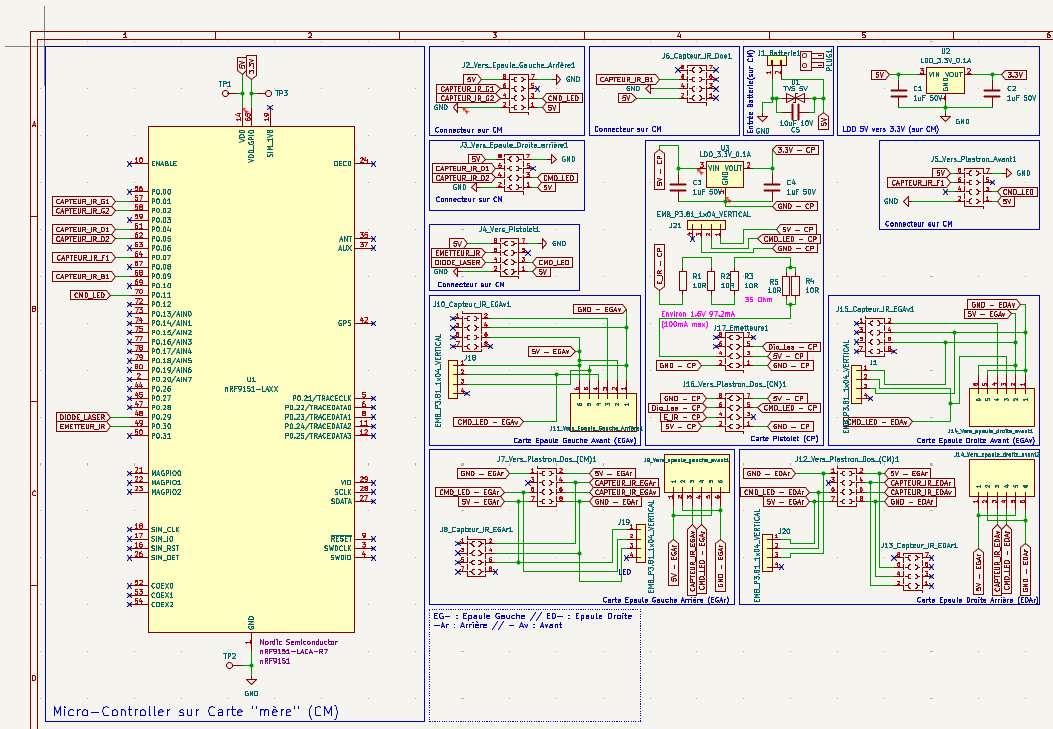
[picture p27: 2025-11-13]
Images/Schematic1.0_Avant.png

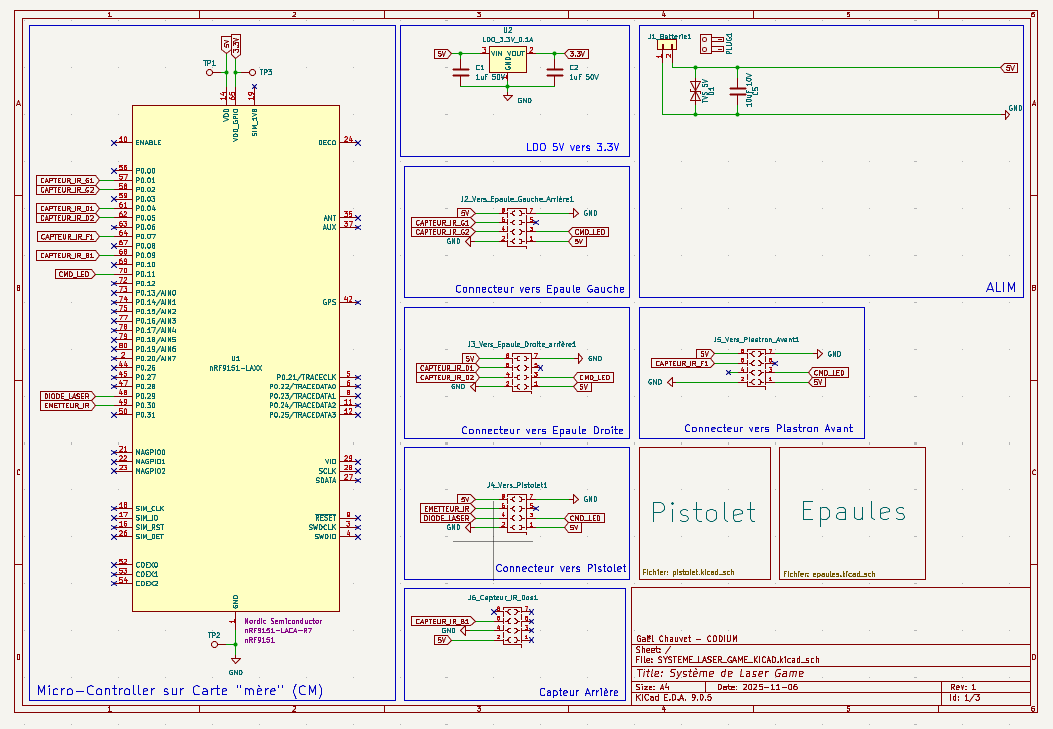
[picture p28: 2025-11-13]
Images/Schematic1.0_Après.png

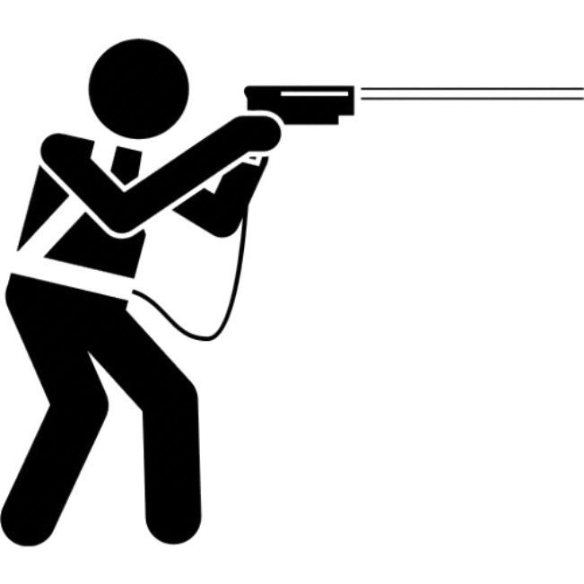
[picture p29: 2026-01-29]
CR/Img/Pres_LaserTag_Equipement.png

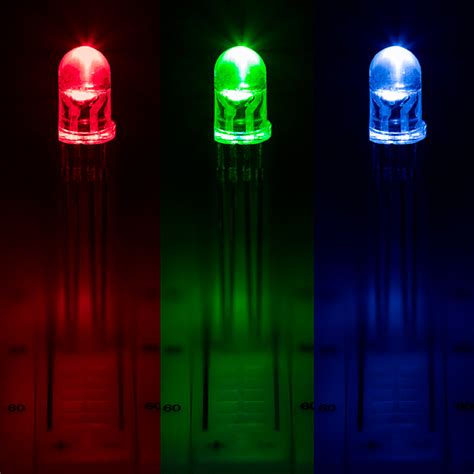
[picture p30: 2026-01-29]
CR/Img/Pres_RGB_4pins.jpeg

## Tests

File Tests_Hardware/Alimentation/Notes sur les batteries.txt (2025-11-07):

Si une batterie de 100 Ah est déchargée avec un courant constant de 5 A, la batterie sera entièrement déchargée au bout de 20 heures.

Fonctionnement chargeur batterie NORDIC du nPM1300 PMIC : https://docs.nordicsemi.com/bundle/ps_npm1300/page/chapters/charger.html

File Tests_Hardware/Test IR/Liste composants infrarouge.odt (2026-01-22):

Capteurs IR :9

- TSOP34338
  - https://www.digikey.fr/fr/products/detail/vishay-semiconductor-opto-division/TSOP34338/1768187
  - marche bien avec : TSAL6200
- TSOP38438 ou TSOP38238 (soit AGC2 ou AGC4)
  - le AGC définit le niveau de suppression de bruit (le 4 supprimant + le bruit que le 2)
  - https://www.digikey.fr/en/products/detail/vishay-semiconductor-opto-division/TSOP38238/1681362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
  - Meilleur choix pour du NEC
  - Angle mi-intensité : 45°
  - longueur d’onde peak = 950nm
  - réellement utilisé pour le module capteur IR du ELEGOO Arduino Super Starter Kit

Diode IR :

- TSAL6200
  - https://www.digikey.fr/fr/products/detail/vishay-semiconductor-opto-division/TSAL6200/1681339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
  - marche bien avec : TSOP34338
- MT5900-IR
  - https://www.digikey.fr/fr/products/detail/marktech-optoelectronics/MT5900-IR/5956247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
  - « relative radiant intensity » + élevée que la précédente (pour If = 100mA)(Angle de vue 20°)
  - Peut monter à If = 1A.
  - Attention la longueur d’onde peak est de 940nm

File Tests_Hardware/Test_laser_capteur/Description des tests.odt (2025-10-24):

Au préalable on va vérifier le bon fonctionnement du laser et du capteur avec une suite de 0 et de 1 envoyés à un intervalle régulier.

L’idée est d’envoyer 10 trames sous différentes conditions et de voir si elles sont toute bien reçues.
Les trames en questions sont composées de signaux numériques (0 ou 1) ( 8 fois ≤=> 8 bit )

Pas besoin de modulation particulière, tant que le « temps bit » du récepteur et de l’emetteur est le même.

Les mesures seront prises entre 5cm et 5m (dans la mesure du possible).

Et avec un angle incident entre -60° à -60° avec un intervalle raisonnable.

Toutes les infos et les résultats seront consigné dans un document de type .ods.

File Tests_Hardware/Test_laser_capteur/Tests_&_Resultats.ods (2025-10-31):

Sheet: Format Test
Distance : (à 0°) | Résultats | Angle : (à ?? de distance) | Résultats
5cm |  | -60°
10cm |  | -45°
50cm |  | -10°
100cm |  | 0°
2,5m |  | 10°
5m |  | 45°
 |  | 60°

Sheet: Fonctionnement
Période d’oscillation max : | entre 10-15us | 20us

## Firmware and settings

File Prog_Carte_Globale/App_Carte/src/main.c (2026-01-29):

#include <zephyr/kernel.h>
#include <zephyr/logging/log.h>
#include <zephyr/devicetree.h>
#include <zephyr/drivers/gpio.h>
#include <zephyr/drivers/pwm.h>
#include "capteurs_Tir.h"
#include "LTE-M.h"

#define RGB_4P_R DT_NODELABEL(pwm_led_r)
#define RGB_4P_G DT_NODELABEL(pwm_led_g)
#define RGB_4P_B DT_NODELABEL(pwm_led_b)

#define TEST_LED_NODE DT_NODELABEL(led_t_0)

static const struct pwm_dt_spec led_RGB_R = PWM_DT_SPEC_GET(RGB_4P_R);
static const struct pwm_dt_spec led_RGB_G = PWM_DT_SPEC_GET(RGB_4P_G);
static const struct pwm_dt_spec led_RGB_B = PWM_DT_SPEC_GET(RGB_4P_B);
static const struct gpio_dt_spec test_LED = GPIO_DT_SPEC_GET(TEST_LED_NODE, gpios);


LOG_MODULE_REGISTER(main, LOG_LEVEL_DBG);

void lED_react(void)
{
        gpio_pin_set_dt(&test_LED, 0);

        k_sleep(K_MSEC(3000));

        gpio_pin_set_dt(&test_LED, 1);
}       


int main(void)
{

        gpio_pin_configure_dt(&test_LED, GPIO_OUTPUT_INACTIVE);


        init_capteursTir_module();
        init_LTE();

        LOG_DBG("All init functions done");
        k_sleep(K_SECONDS(1));
        LOG_DBG("Starting main loop...");

        gpio_pin_set_dt(&test_LED, 1);

        unsigned long reicv_data_value;

        while (1)
        {
                if (get_isDataDecoded())
                {
                        get_decoded_results_value(&reicv_data_value);
                        if (reicv_data_value != 0)
                        {
                                LOG_DBG("Decoded Result: %08lX \n", reicv_data_value);
                                send_hit_info(reicv_data_value);
                                reset_decoded_results_status();
                                 lED_react();
                        }
                        else{
                                LOG_ERR("Error empty data received");
                        }

                }

                k_sleep(K_MSEC(100));
        }

        return 0;
}

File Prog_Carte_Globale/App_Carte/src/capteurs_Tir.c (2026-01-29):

#include <zephyr/kernel.h>
#include <zephyr/logging/log.h>
#include <zephyr/devicetree.h>
#include <zephyr/drivers/gpio.h>
#include <zephyr/drivers/led.h>
#include <zephyr/drivers/pwm.h>

#include "capteurs_Tir.h"
#include "../../Lib/NEC/NEC.h"

// initialize logger
LOG_MODULE_REGISTER(capteur_tir, LOG_LEVEL_DBG);

// ----- GPIO and DEVICES DEFINITIONS FROM NODES ----- //

// Dk LED for debugging emission and reception
static const struct gpio_dt_spec led1 = GPIO_DT_SPEC_GET(LED1_NODE, gpios);
static const struct gpio_dt_spec led2 = GPIO_DT_SPEC_GET(LED2_NODE, gpios);
static const struct gpio_dt_spec led3 = GPIO_DT_SPEC_GET(LED3_NODE, gpios);

// IR receiver node
static const struct gpio_dt_spec irecv = GPIO_DT_SPEC_GET(IR_REICV_NODE, gpios);

// IR and LASER emitter nodes (respectively)
static const struct pwm_dt_spec irmitterPWM_dt = PWM_DT_SPEC_GET(IR_EMIT_NODE);
static const struct gpio_dt_spec lasmitter = GPIO_DT_SPEC_GET(LASER_EMIT_NODE, gpios);

// Switch used as trigger for IR emission
static const struct gpio_dt_spec switch2 = GPIO_DT_SPEC_GET(SW2_NODE, gpios);

// GPIO used as trigger for IR emission
static const struct gpio_dt_spec pwmOut0 = GPIO_DT_SPEC_GET(PWM_NODE, gpios);

// ----- DEFINITION OF WORKQUEUES AND STACK AREAS ----- //

struct k_work_q reicv_work_q;
struct k_work_q emit_work_q;
struct k_work_q decode_work_q;

K_THREAD_STACK_DEFINE(reicv_stack_area, REICV_STACK_SIZE);
K_THREAD_STACK_DEFINE(emit_stack_area, EMIT_STACK_SIZE);
K_THREAD_STACK_DEFINE(decode_stack_area, DECODE_STACK_SIZE);

// ----- DEFINITION OF WORK VARIABLES ----- //

struct k_work lR_IR_Work;
struct k_work emitIR_Work;
struct k_work decodeIR_Work;

struct k_work_delayable lR_IR_DelayableWork;
struct k_work_delayable emitIR_DelayableWork;
struct k_work_delayable decode_IR;

// ----- DEFINITION OF STRUCTURES FOR IR RECEPTION ----- //

irparams_t irParams = {.recvState = STATE_IDLE, .timer = 0, .rawlen = 0};
decoded_result_t decodedResult = {.value = 0, .bits = 0};
unsigned long lastDecodedValue = 0;
bool isDataDecoded = false;

// ----- OTHERS DEFINITIONS ----- //

// init data to send
unsigned long dataToSend = 0xAFAF1234;

// init callback de l'interruption de la gachette
static struct gpio_callback switch2_cb_data;

// ----- GPIO INTERRUPT AND WORKHANDLER FOR IR EMISSION AND RECEPTION ----- //

// ISR that detect when the trigger (button) is pressed
void trigger_pulled(const struct device *dev, struct gpio_callback *cb, uint32_t pins)
{
    LOG_DBG("Switch 2 Pressed");
    k_work_schedule_for_queue(&emit_work_q, &emitIR_DelayableWork, K_MSEC(10));
}

// workhandler that call the listening routine to get raw IR signals
void lR_IR_WorkHandler(struct k_work *work)
{
    uint8_t rawSignal = gpio_pin_get_dt(&irecv);

    // for debug with led
    int val, val2;
    val = rawSignal;
    gpio_pin_set_dt(&led1, val);
    val2 = gpio_pin_get_dt(&pwmOut0);
    gpio_pin_set_dt(&led3, val2);

    // call the listening routine
    lR_IR_Receive(&irParams, rawSignal);

    // reschedule the workhandler
    k_work_reschedule_for_queue(&reicv_work_q, &lR_IR_DelayableWork, K_USEC(TICK_LENGHT));
}

// workhandler that emit IR signals after the trigger was pulled
void emitIR_WorkHandler(struct k_work *work)
{

    gpio_pin_toggle_dt(&led2);
    // dataToSend = 0xABCDEF12;

    while (gpio_pin_get_dt(&switch2) == 1)
    {

        gpio_pin_set_dt(&lasmitter, 1); // turn on laser
        sendNEC(dataToSend);            // example data to send
        // LOG_DBG("TIR");
        gpio_pin_set_dt(&lasmitter, 0); // turn on laser

        k_sleep(K_MSEC(100)); // cooldown
    }

    gpio_pin_toggle_dt(&led2);
}

// workhandler that decode the raw IR signals regularly
void decodeIR_WorkHandler(struct k_work *work)
{

    // decode the received data
    int res = decodeNEC(&irParams, &decodedResult);
    if (res == 0)
    {
        LOG_DBG("Decoded Result: 0x%08lX, bits: %d, res: %d \n", decodedResult.value, decodedResult.bits, res);
        isDataDecoded = true;
        lastDecodedValue = decodedResult.value;
    }
    else
    {
        // LOG_ERR("Decoding failed with res: %d ", res);
        if (res == 2)
        {
            LOG_ERR("(Invalid bit detected)");
        }
        if (res == 1)
        {
            // LOG_ERR("(Invalid start pulse)");
        }
    }

    // reschedule the workhandler
    k_work_reschedule_for_queue(&decode_work_q, &decode_IR, K_MSEC(100));
}

// ----- DEFINITION OF IR EMISSION FUNCTIONS FROM NEC LIBRARY (TO ADAPT TO THE HARDWARE) ----- //

// turns on the PWM for "duration" microseconds
void sendPulse(int duration)
{
    pwm_set_dt(&irmitterPWM_dt, PWM_USEC(28), PWM_USEC(9)); // set duty cycle to 25% 38kHz/4 = 9500Hz
    k_sleep(K_USEC(duration));
}

// turns off the PWM for "duration" microseconds
void sendSpace(int duration)
{
    pwm_set_dt(&irmitterPWM_dt, 0, 0); // turn off PWM
    k_sleep(K_USEC(duration));
}

// ----- INIT OF CAPTEURS & TIR MODULE ----- //
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

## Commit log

2025-10-23 Premier commit d'init et ajouts des premiers fichiers
2025-10-24 Dossier tests Arduino et MàJ des docs et des compos
    [Tests_&_Resultats.ods]
2025-10-31 Test IR et ajout des composants IR
    [Tests_&_Resultats.ods, codium.kicad_pcb, codium.kicad_sch]
2025-11-07 Recherches d'alimentation et début du KiCad
    [SYSTEME_LASER_GAME_KICAD.kicad_sch]
2025-11-07 réalisation des tests, et fixation des nombres de composants sur le KiCad
    [SYSTEME_LASER_GAME_KICAD.kicad_pcb, SYSTEME_LASER_GAME_KICAD.kicad_sch]
2025-11-13 Finalisation test IR et amélioration CAO sur KiCad
    [SYSTEME_LASER_GAME_KICAD.kicad_pcb, SYSTEME_LASER_GAME_KICAD.kicad_sch, epaules.kicad_sch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]
2025-11-14 changement de plan on oublie KiCad et on passe sur le nRF9160 SDK
    [pistolet.kicad_sch]
2025-12-04 ajout du maintient de la gachette
2025-12-05 Ajout circuit allumant le LASER pendant l'émission IR
2025-12-12 test du Ruban LED SK6812 non-concluant passage possible à la tech LTE-M pour avancer
2026-01-09 LTE-M fonctionnel début de l'établissement du serveur
2026-01-16 Etude des LEDs 4 pins et implémentation dans une application séparée
2026-01-22 correction application principale et avancement CR
    [capteurs_Tir.c, capteurs_Tir.h, main.c]
2026-01-23 Rajout des LEDs RGB 4 pins, avancement du rapport
2026-01-29 commit correct, les vidéos lourdes n'ont jamais existés en ligne
    [capteurs_Tir.c, main.c, test_emission_IR.ino]
2026-01-30 Compte-Rendu de PFE V2
2026-01-30 Avancement Script Présentation et réorganisation des fichiers
    [SYSTEME_LASER_GAME_KICAD.kicad_pcb, SYSTEME_LASER_GAME_KICAD.kicad_sch, Tests_&_Resultats.ods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]
2026-01-30 Update README with project details and structure
    Added project description and details about the software prototype and directory structure.
